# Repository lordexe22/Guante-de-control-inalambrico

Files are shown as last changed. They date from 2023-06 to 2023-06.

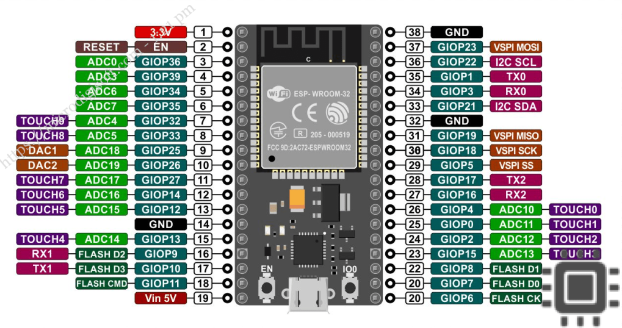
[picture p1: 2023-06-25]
imagenes/ESP32-pinout - Receptor.png

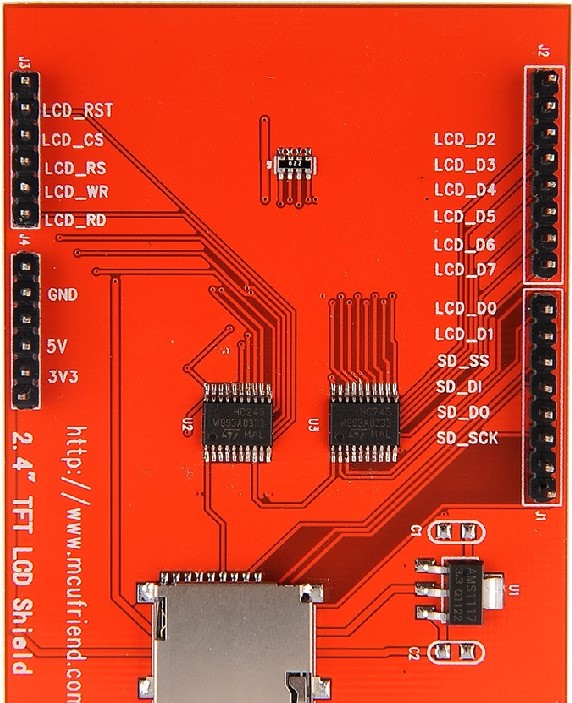
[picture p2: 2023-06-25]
imagenes/TFT-ILI9341-pinout.jpg

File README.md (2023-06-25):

# Guante de control remoto inalámbrico

## Secciones
- **Inforrmes**: En esta sección se encuentra el archivo ***informe.pdf*** en el cual se desarrolla en detalle el proceso de contrucción del proyecto.
- **PCB**: Contiene los archivos de desarrollo de los PCB de las distintas placas involucradas en el proyecto, también se incluyen los PDF con la carilla lista para imprimir cada una de las placas.
- **imagenes**: Catálogo de imágenes usadas para el desarrollo del informe
- **sensores**: Catálogo de imágenes de los sensores implementados en el proyecto, las mismas son usadas para el modelado 3D y las animaciones usadas en la presentación.
- **Sketchs**: Contiene el código implementado en los módulos ESP32 y en el ATMEGA328P, donde:
    - **ESP32emisor** es el código de control del ATMEGA328P con el cual se controla la pantalla táctil
    - **ESP32receptor** es el código del ESP32 que actua como transmisor de datos en el guante
    - **ESP32receptor_brazo** es el código del ESP32 que actua como receptor de datos en la placa conectada al brazo robótico
___
## Presentación
https://www.youtube.com/watch?v=zHHjbapvvzc

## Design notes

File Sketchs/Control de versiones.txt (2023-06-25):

TFTLCD_V1.0 >> las opciones de la pantalla tactil se eligen y se le da a la opcion de reproducir para enviar el codigo correspondiente

TFTLCD_V1.1 >> ahora las opciones se seleccionan presionando dos veces el boton de interes
            >> se agrego el comando "reproducir rutina" con lo cual podemos observar el estado de las rutinas generadas en la memoria SD 

----------------------------------------------------------------------------------------------------------------------------------------------------------

ESP32emisor_V1.0 >> version sin terminar, funcionaba con la mayoria de ordenes a excepcion de la orden "transmitir rutina"

ESP32emisor_V1.1 >> se agrego un algoritmo para poder transmitir una rutina al receptor
                 >> funcional con todas las ordenes a excepcion de la orden "reproducir rutina"

ESP32emisor_V1.2 >> el programa trabaja con un solo tipo de estructura que unifica tanto los datos de configuracion como los datos leidos de los sensores
		 >> se agrega una nueva funcionalidad para reproducir una rutina seleccionada en el receptor
                 >> se corrige el booleano que indica la fase o etapa en la cual nos encontramos dentro de la tarea solicitada (b_esDato)

----------------------------------------------------------------------------------------------------------------------------------------------------------

ESP32receptor_V1.0 >> version sin terminar, tiene implementadas todas las funcionalidades que trabajan con los datos enviados por el transmisor, esto 
		   >> incluye todos los usos de la memoria

ESP32receptor_V1.1 >> se incluyen todas las funcionalidades relacionadas con los sensores que activan las rutinas, en esta version los valores se 
                   >> envian por el puerto serial sin modificaciones (version para usar en la simulacion)

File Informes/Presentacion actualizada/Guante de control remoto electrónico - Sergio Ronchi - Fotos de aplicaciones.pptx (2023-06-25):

## Guante de control remoto electrónico

BERARDI, Nahuel
PUIG, Walter
RONCHI, Sergio J. C.
Director de Tesis: VICARIO, Sebastián

## Fundamentación del proyecto

- El proyecto consiste en la elaboración de un guante de control electrónico inalámbrico dotado de sensores de movimiento, un sistema de almacenamiento de datos y una interface de usuario táctil.

## Diagrama en bloques del guante y del receptor

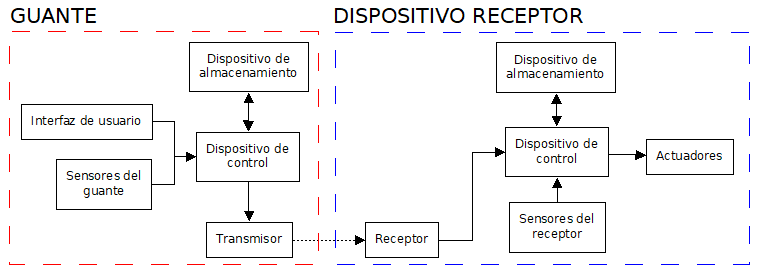
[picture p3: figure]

## Imagen del guante de ambos lados

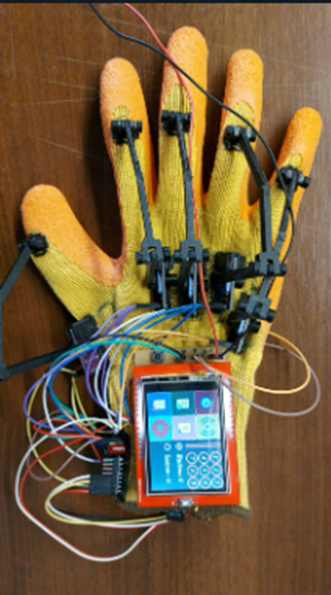
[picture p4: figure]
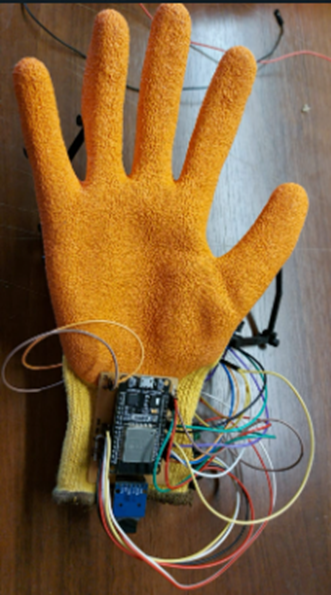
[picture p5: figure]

Sensores de Movimiento

Núcleo ESP32

Pantalla LCD

Módulo de memoria

LEDS

## Sensores de movimiento del guante

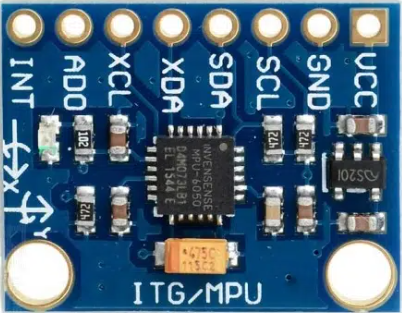
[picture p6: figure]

Acelerómetro
Giróscopo

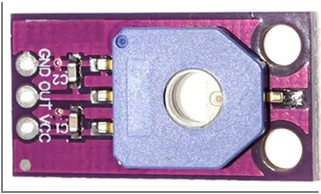
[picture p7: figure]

Sensor de giro

## MENÚ DE PANTALLA

Cambiar sensor

Reproducción en tiempo real

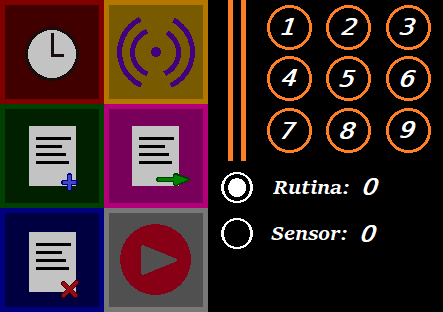
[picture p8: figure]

Teclado Numérico

Transmitir rutina

Crear nueva rutina

Seleccionar Rutina

Borrar rutina

Seleccionar Sensor

Reproducir rutina

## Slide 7

- Seguiría con diagramas en bloque del funcionamiento del guante

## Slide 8

- Acá ocuparíamos 3 ó 4 diapos para el brazo

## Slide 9

- Video de movimiento del guante y del brazo

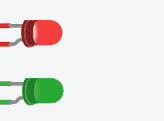
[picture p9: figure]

## Para qué serviría? aplicaciones

- Disponer de un guante con 11 grados de libertad, es decir, 11 datos de movimientos, independientes entre sí, nos abre un abanico bastante amplio de aplicaciones a implementar.
- Por un lado, y en nuestro ejemplo, estamos moviendo un brazo robótico, en tiempo real, o a través de rutinas guardadas.
- Pero podríamos implementar este guante, en otras aplicaciones, tales como:
- Maniobrar un dron.
- Interactuar con realidad virtual, o realidad aumentada.
- Usarlo como periférico para un video juego.

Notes: Disponer de un guante con 11 grados de libertad, es decir, 11 datos de movimientos, independientes entre sí, nos abre un abanico bastante amplio de aplicaciones a implementar.
Por un lado, y en nuestro ejemplo, estamos moviendo un brazo robótico, en tiempo real, o a través de rutinas guardadas.
Pero podríamos implementar este guante, en otras aplicaciones, tales como:
Maniobrar un dron.
Interactuar con realidad virtual, o realidad aumentada.
Usarlo como periférico para un video juego.

## Para qué serviría? aplicaciones

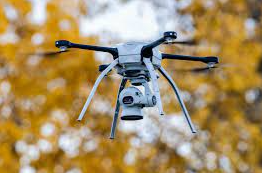
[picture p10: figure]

Dirigir un dron

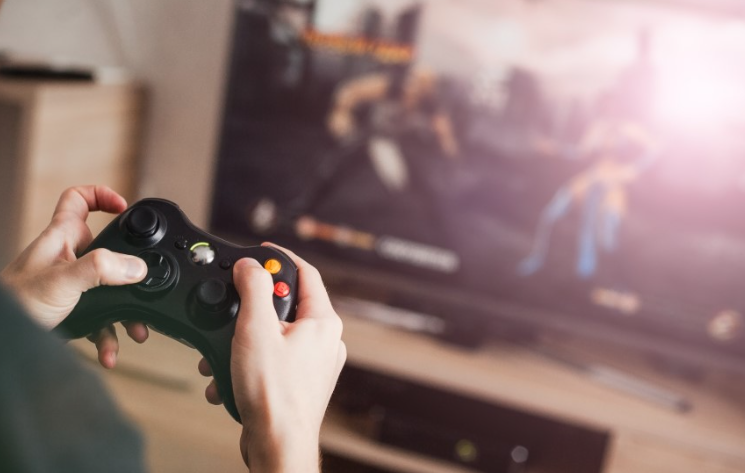
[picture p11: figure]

Videojuegos

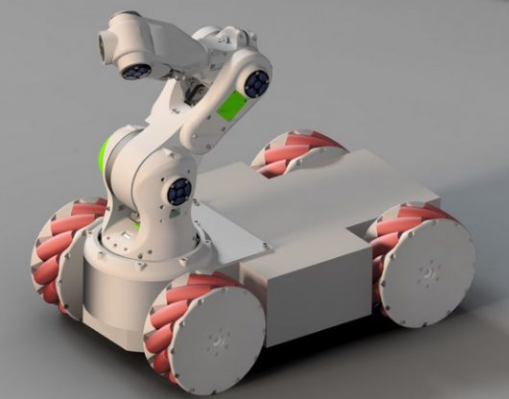
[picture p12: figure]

Vehículo Robot

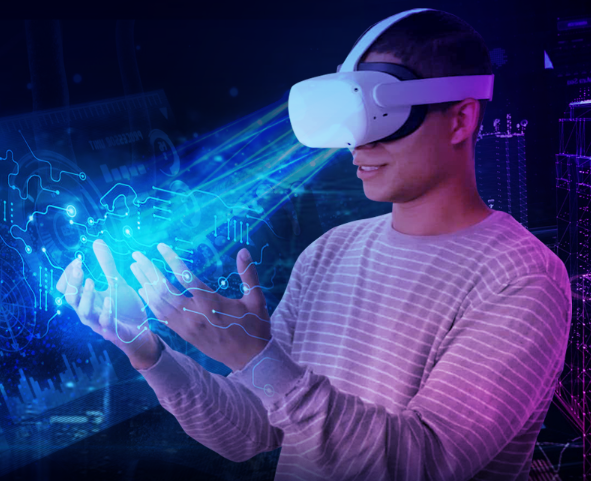
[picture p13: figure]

Realidad Virtual

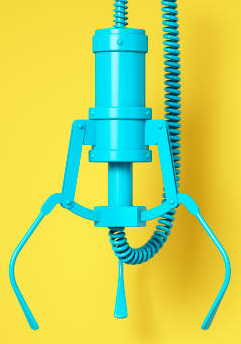
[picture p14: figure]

Garra Robótica

## Alguna pregunta del comité evaluador?

## Gracias por su atención

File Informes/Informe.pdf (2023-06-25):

## Universidad Tecnológica Nacional

## Proyecto Final

# Guante de control remoto electrónico

Autores:

- Berardi, Nahuel Matías
- Puig, Walter Ezequiel
- Ronchi, Sergio Juan Carlos

Director:

- Vicario, Sebastián

Proyecto final presentado para cumplimentar los requisitos académicos

para acceder al título de Ingeniero Electrónico en la

## Facultad Regional Paraná

Diciembre de 2022

## Declaración de autoría:

Yo/nosotros declaro/declaramos que el Proyecto Final “Guante de control remoto” y el trabajo realizado son propio/s. Declaro/declaramos:

- Este trabajo fue realizado en su totalidad, o principalmente, para acceder al título de grado de Ingeniero Electrónico, en la Universidad Tecnológica Nacional, Regional Paraná.
- Se establece claramente que el desarrollo realizado y el informe que lo acompaña no han sido previamente utilizados para acceder a otro título de grado o pre-grado.
- Siempre que se ha utilizado trabajo de otros autores, el mismo ha sido correctamente

citado. El resto del trabajo es de autoría propia.

- Se ha indicado y agradecido correctamente a todos aquellos que han colaborado con el presente trabajo.
- Cuando el trabajo forma parte de un trabajo de mayores dimensiones donde han

participado otras personas, se ha indicado claramente el alcance del trabajo

realizado.

Firmas:

•

•

•

Fecha: 30/12/2022

## Agradecimientos:

En primer lugar, deseamos expresar nuestro agradecimiento a Sebastián Vicario, nuestro profesor guía en este Proyecto Final. Él ha sabido acompañarnos y guiarnos en

este trayecto tan importante de nuestra carrera, poniendo su tiempo a nuestra disposición, y brindando su vasto conocimiento y experiencia, sin dejar de lado su constante buen humor. ¡Gracias Sebastián!

A la comunidad educativa de la Universidad Tecnológica Nacional, Facultad Regional

Paraná que nos brindaron el lugar y las herramientas necesarias para desarrollar este proyecto.

Berardi, Nahuel Matías

Puig, Walter Ezequiel

Ronchi, Sergio Juan Carlos

## Universidad Tecnológica Nacional

# Abstract

## Facultad Regional Paraná

## Ingeniero en Electrónica

# Guante de control remoto electrónico

Berardi, Nahuel Matías

Puig, Walter Ezequiel

Ronchi, Sergio Juan Carlos

Abstract:

This article seeks for the incorporation of new technologies in remote applications

that require performing repetitive tasks through a peripheral based on an electronic control

glove.

The project consists in the elaboration of an electronic control glove equipped with

movement sensors, a data storage system and a tactile user interface. It is sought that it be

able to control other electronic devices in real time and on the other hand that can create, transmit and reproduce movement routines that are activated by a sensor of the receiving

device. To achieve this, not only the glove is enough, it is necessary to implement a control module that commands the receiving device, which in this case is a robotic arm, which is why an appropriate circuit must be made for its control.

For its elaboration, the communication and control system between both devices is based on the ESP32 wireless module, the data storage is done through SD memory reader

modules, the mechanical system of the glove and the robotic arm were elaborated by means of 3D printing, Movement capture was done with gyro sensors and the module with accelerometer and gyroscope MPU6050. Finally, the user interface consists of a touch LCD

screen controlled by an ATMEGA328P on the glove and a 2x16 LCD screen on the receiver

plate incorporated into the arm.

The result obtained is a system that allows the user to remotely control the robotic arm in real time and store movement routines in the SD memory so that they can be

reproduced when one of the sensors connected to it is activated. However, as the system is similar for any type of receiver, it has the potential to control other devices such as drones,

robots, toys, and more.

Keywords:

Data

Memory

Movement

Routine

Wireless

Resumen:

Este artículo busca la incorporación de nuevas tecnologías en aplicaciones remotas

y que requieran realizar tareas repetitivas mediante un periférico basado en un guante de control electrónico.

El proyecto consiste en la elaboración de un guante de control electrónico inalámbrico dotado de sensores de movimiento, un sistema de almacenamiento de datos y una interface de usuario táctil. Se busca que sea capaz de controlar otros dispositivos

electrónicos en tiempo real y por otro lado que pueda crear, transmitir y reproducir rutinas de movimientos que sean accionadas mediante la activación de algún sensor del dispositivo

receptor. Para lograr esto no solo basta con el guante, sino que es necesario implementar un módulo de control que comande el dispositivo receptor, el cual en este caso es un brazo

robótico, es por esto que se debe realizar un circuito acorde para su control.

Para su elaboración, el sistema de comunicación y control entre ambos dispositivos está basado en el módulo inalámbrico ESP32, el almacenamiento de datos se hace

mediante módulos de lectores de memoria SD, el sistema mecánico del guante y del brazo robótico fueron elaborados mediante impresión 3D, la captura de movimientos se realizó

con sensores de giro y con un módulo que incorpora un acelerómetro y un giroscopio en un solo chip (MPU6050). Finalmente, la interface de usuario está constituida por una pantalla

LCD táctil controlada por un ATMEGA328P en el guante y una pantalla LCD de 2x16 en la

placa receptora incorporada al brazo.

El resultado obtenido es un sistema que le permite al usuario controlar remotamente en tiempo real el brazo robótico y almacenar rutinas de movimiento en la memoria SD para que sean reproducidas al activarse uno de los sensores conectados al mismo. Sin embargo,

como el sistema es similar para cualquier tipo de receptor, tiene el potencial para controlar otros dispositivos como drones, robots, juguetes y más.

Palabras Clave:

Datos

Inalámbrico

Memoria

Movimiento

Rutina

## Índice:

1.4.2. DEXTAROBOTICS DEXMO haptic feedback exoskeleton gloves.........3
2.8. Procesamiento de la información (acelerómetros/giroscopios/sensores).....33

5.3. Comparar con otros productos existentes a modo debate. Remarcando

## Lista de Figuras:

Figura 19: a) Principio de funcionamiento del Acelerómetro, b) Arquitectura interna

Figura 22: Variación de los ejes del acelerómetro cuando se lo rota sobre un eje .21

Figura 33: Conexionado de los botones de start, stop, el potenciómetro selector y el

Figura 39: Imagen del conexionado del servomotor de la muñeca con la palma....42

Figura 40: Ubicación del servomotor de la muñeca dentro de la impresión 3D ......43

## Lista de Tablas:

## Lista de Abreviaciones y Símbolos

## Lista de abreviaciones

LiPo | Litio y polímero
SCM | Supply Chain Management (Administración de la cadena de suministro)
SD | Secure Digital
LCD | Liquid Cristal Display (pantalla de cristal líquido)
PCB | Printed Circuit Board (placa de circuito impreso)
HMI | Human-Machine Interface (interfaz humano-maquina)
n° | Número
IMU | Inertial Measurment Units
MEMS | MicroElectroMechanical Systems
[°/s] | Grados por segundo
MPU | Multiple Process Unit (Unidad de proceso múltiple)
HTML | HyperText Markup Language (Lenguaje de Marcas de Hipertexto)
CSS | Cascading Style Sheets (hojas de estilo en cascada)
ROM | Read Only Memory (‘memoria de solo lectura’)
SDHC | Secure Digital High Capacity
MAC | Media Access Control
I2C | inter integrated circuits
ms | mili-segundos
ADC | Analog to Digital Converter (Conversor Analógico Digital)

## Lista de símbolos

a | Aceleración
dV | Diferencia de velocidad
dt | Diferencia de tiempo
F | Fuerza
m | Masa
θX | Angulo de inclinación con respecto al eje X
θY | Angulo de inclinación con respecto al eje Y
aX | Acelerómetro del eje X
aY | Acelerómetro del eje Y
aZ | Acelerómetro del eje Z
θX0 | Angulo con respecto al eje X anterior
θY0 | Angulo con respecto al eje Y anterior
ωX | Velocidad angular con respecto al eje X
ωY | Velocidad angular con respecto al eje Y
∆t | Intervalo de tiempo
a(PWM) | Valor de la aceleración para luego generar la PWM
amax | Máximo valor del acelerómetro
amin | Mínimo valor del acelerómetro
k | Constante de ajuste
gx | Valor de la velocidad angular sobre el eje X leído del giroscopio
gactual | Valor de la velocidad angular en la medición actual leído del giroscopio
ganterior | Valor de la velocidad angular en la medición anterior leído del giroscopio
tactal | Valor del tiempo de la medición actual
tanterior | Valor del tiempo de la medición anterior

## Dedicado a:

Un trabajo de desarrollo es también fruto del reconocimiento y del apoyo vital que

nos ofrecen las personas que nos estiman, sin las cuales no tendríamos la fuerza y energía que nos anima a crecer como personas y como profesionales.

Es por esto que deseamos dedicarle este informe a aquellas personas que han estado con nosotros a lo largo de todos estos meses brindándonos su apoyo de manera

incondicional.

Berardi Nahuel:

Este proyecto lo dedico principalmente a mi mamá y mi papá, quienes me han brindado su apoyo y contención a lo largo de estos años, gracias a eso pude dedicarme por completo a esta etapa de mi vida. Hago una especial dedicatoria a mi hermana, que siempre

está presente para motivarme y consolarme cuando lo necesito, es la persona que me apoya para seguir adelante, sin importar el tipo de problema que enfrente.

Finalmente, y no menos importante, a mis amigo y seres queridos por motivarme a continuar ¡gracias a todos!

Puig Walter:
Mi dedicatoria va principalmente para mi familia quienes me han brindado su amor y

apoyo a lo largo de estos años para permitirme dedicarme al 100% a superar esta etapa de mi vida. Le hago una dedicatoria especial a Sol quien sin saberlo me ha sabido contener en

las malas y me ha prestado un oído siempre que necesite hablar con alguien. Finalmente, y no menos importante a mi equipo de trabajo con los cuales hemos trabajado codo a codo para finalizar este proyecto y cumplir nuestras metas, ¡gracias a todos!

Ronchi Sergio:

A mis padres, Azucena y Pedro, que desde el Cielo están celebrando este momento.

A mi esposa Patricia, y a mis hijas Delfina y María Paz, nada podría funcionar sin

ellas…

¡A mis amigos y seres queridos, gracias por motivarme siempre a seguir!

1 Introducción | 1

## Capítulo 1: Introducción

1.1. Fundamentación del proyecto.

El proyecto propuesto es un guante de transmisión y control de datos, cuya finalidad es brindarle al usuario la posibilidad de crear fácilmente un conjunto de rutinas de trabajo

que sean accionables mediante sensores o pulsadores sin la necesidad de programar cada

uno de los movimientos que llevará a cabo el dispositivo electrónico que se desee controlar.

Inicialmente el proyecto fue planteado para aplicarse en sistemas de producción que

requieran de un conjunto de rutinas de movimiento repetitivas en el tiempo y que sean accionadas por un sensor. Sin embargo, también se extiende a la posibilidad de controlar

dispositivos de manera remota y en tiempo real, lo cual brinda la funcionalidad adicional de

poder utilizarlo en aplicaciones de alto riesgo, incluso como un medio de entretenimiento (para controlar dispositivos como drones, vehículos de control remoto y periféricos para consolas o PC).

Para esto se propone la creación de un guante de control que estará dotado de varios

sensores que detectarán los movimientos realizados por el usuario y un sistema de transmisión de datos que enviará esta información hacia el dispositivo electrónico que se

desee controlar. La idea es que el guante le permita al usuario tanto la creación, como la gestión y el guardado de distintas rutinas de movimientos que deben ser leídas e

interpretadas por otros dispositivos electrónicos para ejecutar una o varias acciones.

Para lo anterior, es imprescindible que el guante permita el control de dispositivos en tiempo real de forma remota, esto con la finalidad de llevar a cabo tareas manualmente o

bien para darse una idea de cómo se comportarán algunas de las rutinas que se deseen implementar.

### 1.2. Público objetivo

El público objetivo de este proyecto está orientado a toda industria o institución que

se vea en necesidad de controlar remotamente en tiempo real o mediante una rutina de movimientos algún dispositivo electrónico. Sin embargo, según la orientación que tome el proyecto en futuras versiones, podría tener demanda en distintas áreas enfocadas al

entretenimiento.

1 Introducción | 2

Este prototipo brinda facilidades para realizar trabajos que emplean rutinas de movimientos repetitivos como los que se llevan a cabo en cadenas de producción, en dispositivos de maniobras (cocinero inteligente, cama de masaje inteligente, asistentes de

laboratorio, etc.), permitiéndole al usuario la programación de las rutinas necesarias para ejecutar el trabajo deseado. A su vez también permite el control de dispositivos en tiempo

real, lo cual permite al usuario utilizarlo en una amplia gama de aplicaciones que pueden ir desde su uso en trabajos potencialmente peligrosos hasta sistemas de entretenimiento.

### 1.3. Pruebas de concepto

Las prestaciones podrían garantizar, en general, un trabajo más eficiente. Cuando se lo usa en tiempo real de forma remota, un operario que efectúa un trabajo de riesgo,

puede maniobrar en una situación de estrés mucho menor que si estuviera realizando un trabajo riesgoso de manera presencial, lo cual lleva a realizar mejor la tarea.

Para el caso en el que se realizan tareas repetitivas, el proceso se vuelve más económico al no requerir de un empleado que efectúe el trabajo manualmente y más

confiable ya que reduce el margen de error por fatiga.

### 1.4. Análisis de mercado

1.4.1. Guante somatosensorial basado en arduino.

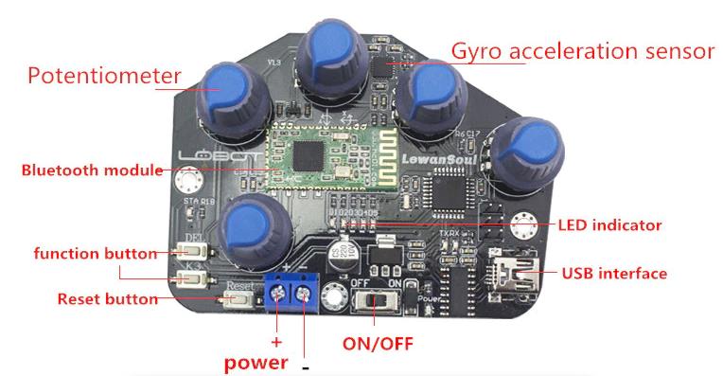
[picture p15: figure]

Figura 1: Guante somato sensorial

Se trata de un guante somato sensorial pensado para la comunicación y control de

distintos tipos de dispositivos. Este modelo comercial permite el control de los dispositivos mostrados en la imagen mediante la aplicación de gestos predefinidos para tal fin.

1 Introducción | 3

Características:

- Guante mecánico de código abierto basado en Arduino; Modelo de chip único:

ATmega328P

- Esquema abierto y código fuente;
- El módulo Bluetooth 4,0 integrado y el sensor de aceleración;
- Proporciona un gran número de rutinas de control que pueden controlar la palma del robot, el brazo robótico, el robot biónico, el coche inteligente

Parámetros del producto:

Modelo de microcontrolador: Arduino

Batería: 7,4 V 2S lipo-batería (integrada)

Tamaño: 147[mm] x 113[mm]

Peso: 0,26[kg]

Precio aproximado: 100 USD

El guante se usa para controlar el robot, el módulo Bluetooth del robot debe trabajar en HC-08. Basado en el Protocolo Bluetooth 4,0.

### 1.4.2. DEXTAROBOTICS DEXMO haptic feedback exoskeleton gloves

Este modelo lee los movimientos que se llevan a cabo con el guante capturando hasta 11 grados de libertad y además su tecnología le brinda al usuario la sensación de

tacto cuando se lo utiliza en entornos de simulación de realidad virtual.

Figura 2: Dextarobotics dexmo

1 Introducción | 4

Para conseguir este efecto, los guantes utilizan un sistema que aplica un torque justo en la dirección contraria a la cual se efectúa el movimiento de la mano, es decir, para conseguir que tengas la sensación de que tus dedos chocan con algo, un mecanismo tira

de ellos hacia atrás justo en el momento preciso.

Dexmo es el guante de retroalimentación de fuerza más portátil del mundo

para investigadores, empresas y consumidores. Proporciona un toque natural e intuitivo que da un toque íntimo del mundo de RV verdaderamente inmersivo.

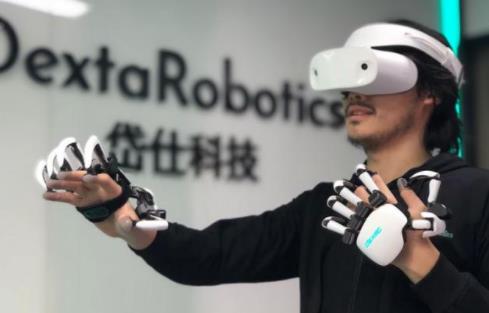
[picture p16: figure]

Figura 3: Dextarobotics dexmo

Dexmo es el primer guante portátil de retroalimentación de fuerza inalámbrica de dos

manos disponible comercialmente del mundo, con captura de movimiento de mano y retroalimentación de fuerza para una experiencia interactiva de retroalimentación de fuerza

más emocionante. Tiene aplicaciones en el área aeroespacial, formación industrial, investigación educativa, rehabilitación médica, modelado de simulación, socialización de juegos y más.

Características:

- Habilidad de capturar movimientos: Dexmo captura un rango completo de

movimientos de la mano del usuario y posee dos grados de libertad en la captura de movimiento de los dedos, permitiendo capturar los movimientos de flexión y

abducción de los mismos.

- Fuerza de respuesta variable: Le permite al usuario sentir el tamaño y la forma de cualquier objeto digital. Los motores detienen la rotación de los dedos de acuerdo al

avatar digital con la que tiene interacción la mano dentro del mundo digital. Dexmo

1 Introducción | 5

también es capaz de generar una fuerza de salida variable, permitiendo al usuario detectar la diferencia en la rigidez de los objetos y detectar por ejemplo la diferencia

entre una piedra y una pelota.

- Simulación de múltiples capas de rigidez: Al combinar el control de software con la capacidad de retroalimentación de fuerza variable, los desarrolladores pueden

describir fácilmente la rigidez de un objeto a través de las librerías de Dexmo y lograr una sensación háptica compleja. Cuando hay un cambio en la rigidez, se pueden

lograr sensaciones como presionar un botón y romper un huevo.

- Mejora de la seguridad: Dexmo está diseñado para ser seguro. La función de

control de salida del par motor controla la fuerza ejercida por el dedo del usuario y desactiva todas las funciones del motor en circunstancias anormales. Además, la salida de torsión máxima de cada módulo de retroalimentación de fuerza de cada

dedo está sujeta a 3[kg.cm] (0,3[N.m]). Un dedo humano puede proporcionar un torque promedio de 7[kg.cm] (0.7[N.m]). Entonces Dexmo nunca causará lesiones.

- Soporte de plataforma: Dexmo viene con su propio SDK, Lib Dexmo. Junto con el complemento de Unity que escribimos, Dexmo funciona con Oculus CV1, HTC Vive,

PSVR, Hololens y potencialmente con cualquier otra solución de VR/MR compatible

con el desarrollo de Unity.

- Comunicación inalámbrica: Comunicación inalámbrica con módulos de 2.4[GHz]

con protocolos de comunicación optimizados, con latencia de 20-50[ms] y rangos de funcionamiento de 5 metros.

- Ligero y portátil: Gracias al diseño liviano de los motores, Dexmo pesa solo 320[g], mientras que los productos existentes que ofrecen funcionalidades similares

generalmente pesan 10 veces más. Permite a los usuarios usar Dexmo cómodamente e ignorar su presencia cuando exploran en realidad virtual.

- Hasta 6 horas de duración de la batería: con los confiables y potentes módulos de batería LiPo de 2000[mAh], Dexmo puede funcionar de forma inalámbrica durante 6

horas con un uso normal.

Precio aproximado: 800 USD

1 Introducción | 6

### 1.4.3. Guantes de control de movimiento Keywish Autos Smart

Figura 4: Guantes de control de movimiento Keywish Autos Smart

El dispositivo de guante de movimiento puede calcular la dirección de inclinación de la palma de 0 a 360 grados en tiempo real. De acuerdo con estos dos parámetros, los usuarios pueden controlar cualquier dispositivo bluetooth, que es adecuado para otros autos inteligentes SCM u otros hogares inteligentes.

Características:

- Guante deportivo de código abierto basado en Arduino; Modelo de chip único: ATmega328P
- Esquema y código de fuente abiertos;
- Posee un módulo Bluetooth y un sensor de aceleración;
- Proporciona una determinada cantidad de rutinas de control que pueden controlar el coche inteligente.

Parámetros del producto:

Modelo de microcontrolador: Arduino

Batería: 9[V]

Precio aproximado: 40 USD

### 1.5. Conclusiones

1 Introducción | 7

En el mercado existe una interesante variedad de guantes con características bien definidas y que se pueden orientar a aplicaciones diferentes. Existen prototipos que proponen una aplicación de los mismos como juguetes educativos, juegos interactivos o

entretenimiento. El diseño implementado en este proyecto busca desde un inicio incorporar una tecnología que, si bien ya existe, no se ve implementada en los campos de interés

mencionados. La intención de este proyecto es sentar las bases para diseñar y construir una herramienta orientada al área industrial y de automatización, sin embargo, por lo visto

hasta ahora la naturaleza del diseño de este prototipo permite darle una gran flexibilidad y con ello la capacidad de poder ampliar su público objetivo y su área de aplicación.

2 Desarrollo | 8

## Capítulo 2: Desarrollo

2.1. Introducción.

El proyecto consiste en un guante al cual se le implementan un conjunto de módulos que le permitirán al usuario la gestión y control de rutinas que se guardan y modifican dentro de una memoria SD. El diagrama en bloques del guante es el siguiente:

Figura 5: diagrama en bloques del guante

En términos generales, los bloques funcionan de la siguiente forma:

- Interfaz de usuario: El usuario interactúa con las opciones disponibles y crea un código acorde, el cual, será enviado al dispositivo de control para efectuar

la tarea solicitada.
- Sensores del guante: Brindan información acorde a la posición de la mano y

los dedos.
- Dispositivo de almacenamiento: Guarda la información acorde a los diferentes tipos de configuraciones y a las rutinas almacenadas.
- Dispositivo de control (guante): Gestiona todos los bloques, ejecuta las tareas solicitadas y evalúa posibles problemas o conflictos para prevenir errores.
- Emisor y receptor: Establecen el medio por el cual se podran comunicar el guante y el dispositivo receptor.
- Dispositivo de control (receptor): Despues de recibir una orden desde el guante, gestiona la memoria y los datos para poner en funcionamiento los

actuadores propios del dispositivo receptor en caso de que así se requiera. Adicionalmente, detecta de manera constante los sensores propios conectados en el receptor, que al activarse ejecutarán la rutina vinculada al mismo. Los datos dentro de la rutina deben ser modificados acorde al tipo de aplicación para lo cual se los utilice.
- Sensores del receptor: Puede tratarse de cualquier tipo de sensor o pulsador

lógico. Cada sensor tiene asignado un número y al activarse el circuito de

control debe reproducir la rutina vinculada al sensor activado.
- Actuadores (receptor): Son propios del dispositivo receptor conectado al

dispositivo de control.

2.2. Funcionamiento general.

El guante posibilita la creación de hasta nueve rutinas, las cuales deben estar vinculadas a un número de sensor. Por ejemplo, si se crea la rutina uno y se la vincula al

sensor tres, entonces cuando en el receptor se active el sensor tres se ejecutará la rutina uno desde la memoria SD del dispositivo receptor. En la siguiente imagen se observa dentro

de la memoria SD que se han creado las rutinas 1, 2, 4 y 6.

Figura 6: Contenido de la memoria SD

La memoria SD cuenta con un archivo llamado Lista.txt en el cual se listan los pares (n° rutina , n° sensor) y al crearse una rutina, por ejemplo la rutina 1, se crea un archivo

‘Rutina_1.txt’ en la cual almacenará los valores que lea en los sensores al momento de su creación. Al abrir el archivo Lista.txt podemos observar a que número de sensor están

vinculadas las rutinas.

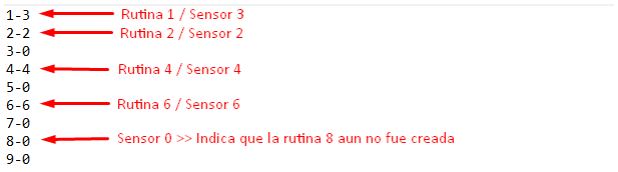
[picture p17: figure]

Figura 7: Contenido del archivo Lista.txt

Si abrimos los archivos de las rutinas, veremos los valores sensados durante su creación.

El guante permite realizar las siguientes operaciones:

1- Reproducción de datos en tiempo real: En este modo el guante lee los sensores y transmite sus valores al dipositivo receptor a una determinada frecuencia. El receptor por su parte, interpreta estos valores y ejecuta una acción acorde a los valores recibidos.

2- Transmisión de rutina: Se envia la configuración (n° rutina , n° sensor) y los valores leídos desde la memoria SD del emisor hacia la memoria SD del receptor.

3- Crear rutina: Crea una rutina y la almacena en la memoria SD del guante. Para ello modificará el par (n° rutina , n° sensor) y leerá los sensores del guante a una frecuencia determinada para almacenar esos valores en la memoria SD.

4- Cambiar sensor: Cambia el número del sensor vinculado a una rutina ya creada dentro de la memoria SD en el archivo Lista.txt, posteriormente transmite un código al dispositivo receptor para que haga lo mismo en su correspondiente memoria SD.

5- Borrar rutina: Elimina la rutina indicada. Para ello, primero actualiza el archivo Lista.txt haciendo que el valor del sensor vinculado a la rutina sea cero, luego elimina el archivo de la rutina indicada, y finalmente envía una orden al receptor para que haga lo mismo en su respectiva memoria SD.

6- Reproducir rutina: Esta modalidad permite seleccionar una rutina ya creada dentro de la memoria SD del guante y reproducirla en tiempo real una vez en el receptor sin guardarla en la memoria del mismo.

### 2.3. Interfaz de usuario:

Este bloque está compuesto por la pantalla LCD táctil ILI9341 y el microcontrolador ATMEGA328P. En principio se habia considerado utilizar una plantilla de pulsadores con una pantalla LCD de 2x16, pero la opción de la pantalla táctil nos otorga las siguientes prestaciones superadoras:

- Permite implementar una gran cantidad de botones en un espacio compacto, ahorrando en este caso la implementación de un PCB con al menos 15 pulsadores y una pantalla LCD de 2x16 o mayor.
- Brinda una interfaz más amigable con el usuario, permitiendo la visualización de la configuración realizada y el estado actual del guante.
- HMI más elegante, compacta y profesional.
- Totalmente controlable con el microcontrolador ATMEGA328P.

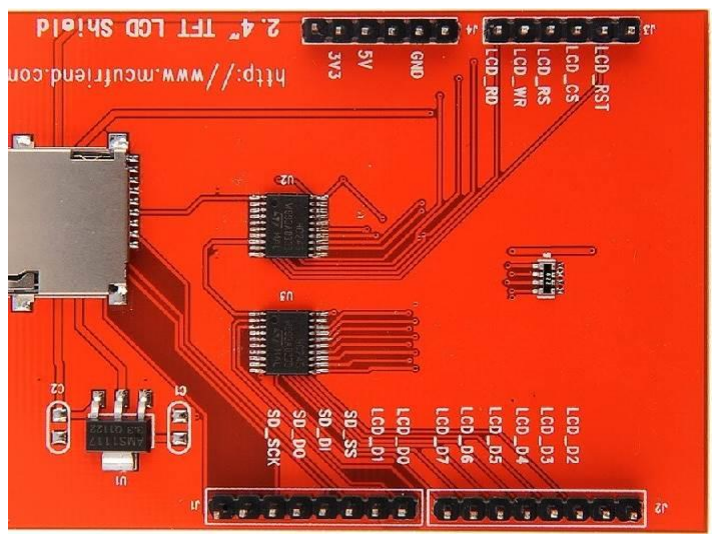
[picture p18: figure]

Figura 8: Pantalla LCD táctil ILI9341 vista de frente y reverso

Figura 9: Atmega328P

Figura 10: Pinout del Atmega328P

El esquema propuesto para la HMI es el siguiente:

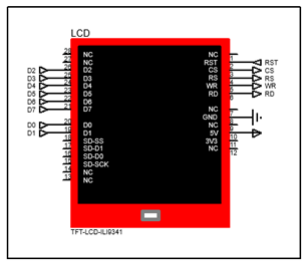
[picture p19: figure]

Figura 11: Conexionado del Atmega328P | Figura 12: Conexionado de la pantalla LCD ILI9341

Figura 13: Puertos de alimentación, oscilador y botón de reset del HMI

El esquema es una conexión básica del microcontrolador con el circuito oscilador y el botón de reset. También cuenta con tres puertos, de los cuales dos de ellos son de

alimentación (uno de entrada y uno de salida) y el otro es para comunicar mediante protocolo UART el ATMEGA328P con el ESP32 del bloque de control. Finalmente se

conecta el microcontrolador con la pantalla LCD táctil, los pines RST, CS, RS, WR y RD se usan para reiniciar la pantalla y que la misma permita visualizar la información,

adicionalmente con la ayuda del resto de los pines (D0 a D7) logramos controlar la componente táctil de la pantalla, que entre otras cosas retorna las coordenadas X, Y y la

presión ejercida sobre la misma, permitiendo saber en qué zona de la pantalla se ejerce presión.

Una vez conocido el esquema implementado para la HMI, queda conocer el software que se implementa sobre el mismo. Para esto se presenta el menú de la pantalla:

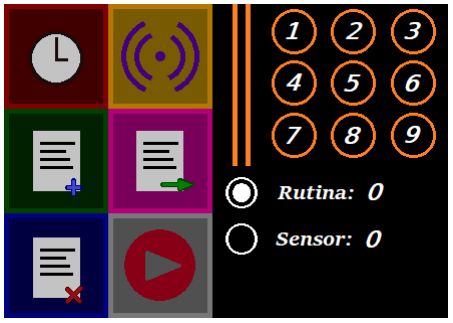
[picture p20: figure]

Figura 14: Diseño de la interfaz del HMI

En la mitad izquierda de la pantalla se hallan los botones correspondientes a las diferentes tareas disponibles, mientras que a la derecha tenemos un teclado numérico y un

selector de rutina y de sensor, que nos permiten indicar sobre qué conjunto se realizará la tarea indicada. Para efectuar una tarea en concreto se deben seleccionar (de ser necesario)

el número de la rutina y del sensor que se involucran en la tarea y posteriormente pulsar dos veces el icono correspondiente. Durante el primer pulso el botón se iluminará y en el segundo quedará marcado con un recuadro rojo indicando que la tarea esta activa.

Figura 15: Estados de los botones de la interfaz del HMI

Si no se presiona por segunda vez el botón, este se “apaga”. A continuación se

presenta una tabla que indica el tipo de datos necesario para cada tarea.

Tarea | ¿Requiere rutina? | ¿Requiere sensor?
1 – Reproducción en tiempo real | NO | NO
2 – Transmitir rutina | SI | NO
3 – Crear nueva rutina | SI | SI
4 – Cambiar sensor | SI | SI
5 – Borrar rutina | SI | NO
6 – Reproducir rutina | SI | NO

Finalmente se indica la tarea asociada a cada uno de los iconos presentados en la pantalla:

Reproducción en tiempo real | Crear nueva rutina
Borrar rutina | Cambiar número de sensor
Transmitir rutina | Reproducir rutina

La lógica dentro del comportamiento de la HMI queda detallada en el siguiente diagrama:

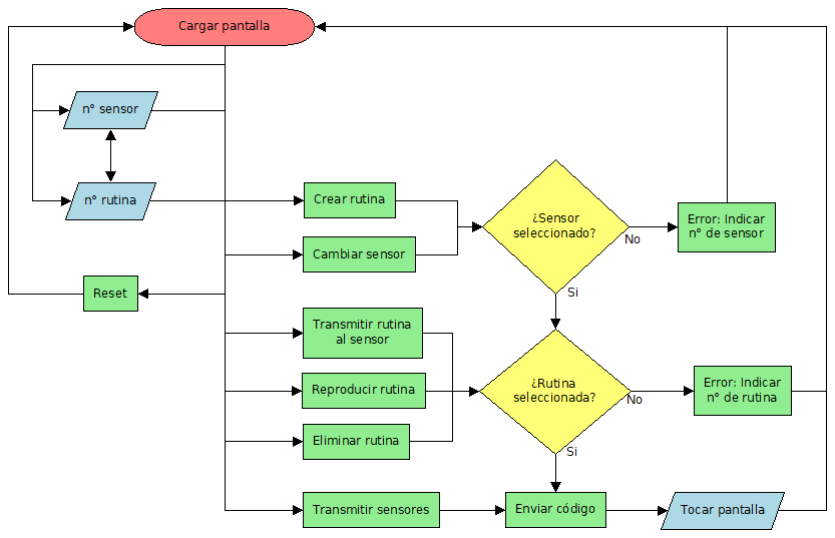
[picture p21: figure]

Figura 16: Diagrama de flujo de la interfaz del HMI

Inicialmente se carga la pantalla del menú principal. Desde este ese punto el usuario puede optar por modificar el número de sensor, el número de rutina, el botón de reset o

bien presionar dos veces alguno de los botones de tareas. Luego de intentar activar alguna tarea, se evalúa si se han llenado los campos necesarios para cada una de ellas y en caso

afirmativo envia un código acorde mediante comunicación I2C hacia el circuito de control.

En caso contrario se podra visualizar en la pantalla un mensaje indicando el campo que falta completar para efectuar la tarea solicitada. Para finalizar la tarea solicitada, basta con

volver a presionar la pantalla en cualquier lugar, esto enviará un código de finalización hacia el circuito de control y reiniciará la pantalla LCD.

El código enviado consiste en tres números separados por guiones, el primero corresponderá a la tarea que se desea ejecutar, el segundo es el número de la rutina

involucrada y el tercero el número del sensor. La única excepción sera el código de cierre para indicar que se desea terminar con la tarea solicitada. Este último código sera 0-0-0.

2.4. Sensores del guante.

La función principal de los sensores en este proyecto es el de capturar los movimientos que el usuario efectúe al mover la mano o los dedos. Por un lado, para detectar

la flexión en los dedos las dos mejores dos opciones disponibles son resistencias flexibles y módulos de sensores de giro. Se pretende analizar cada opción y justificar la elección

tomada.

Resistencias flexibles:

Pros:

- Son mucho más simples de manipular y se pueden colocar directamente sobre el guante para que funcionen.

Contras:

- Requieren una conexión en serie de otra

resistencia en caso de que se desee leer la flexión por variación de tensión y no de corriente.

- Son considerablemente más costosas que los

sensores de giro.
- Son algo frágiles, por lo cual pueden quebrarse por

el desgaste al usarlas.

Figura 17: Resistencia flexible

Módulos de sensores de giro:

Pros:

- | Considerablemente | más | económicos | que | las
| resistencias flexibles.
- No requieren componentes externos, el valor de interés

puede obtenerse directamente de la salida del sensor.

- Compactos, precisos y con un buen rango de
| funcionamiento.

Contras:

- Debe suministrarse 3.3[V] a cada uno de los dispositivos para que funcionen.
- Debe considerarse que no tienen tope, por lo cual, al

girar y sobrepasar su valor máximo, conmutará al valor mínimo y viceversa.

- Requieren implementar un mecanismo externo para lograr rotar su eje al realizar el movimiento de los dedos.

Figura 18: Sensor de giro

Vistas las dos propuestas, se optó por el sensor de giro. La razón principal es que si

bien tienen la desventaja de requerir del diseño de un mecanismo externo que permita la rotación del eje del sensor al flexionar un dedo, esto puede tomarse como una posibilidad para escalar el proyecto y diseñar a futuro un mecanismo más complejo y que permita el

uso de más sensores de giro, permitiendo por ejemplo la lectura del movimiento lateral de los dedos y aumentando así los grados de libertad y la cantidad de señales que pueden

interpretarse. El diseño y la impresión 3D de los módulos para conectar los sensores se detallan al final del capítulo.

Ya analizados los sensores de los dedos, queda pendiente medir la posición y rotación de la mano en el espacio con respecto al codo. Para ello también optamos por dos

modelos. El primero y más sencillo es simplemente conectando algunos potenciómetros en las zonas próximas al codo y la muñeca, así el movimiento y giro de los mismos generarán

las variaciones que deseamos medir para saber que estamos efectivamente flexionando el codo o bien rotando la muñeca. La segunda opción, que finalmente fue la adoptada en este

proyecto, pese a resultar más compleja, pero mucho más interesante es la utilización de un módulo que cuenta internamente con un sistema de giroscopios y acelerómetros con los

cuales podamos saber exactamente como se está produciendo el movimiento de la mano en el espacio.

El módulo escogido es el MPU6050. Es una unidad de medición inercial o IMU

(Inertial Measurment Units) de 6 grados de libertad (DoF), este dispositivo combina un acelerómetro de 3 ejes con un giroscopio de 3 ejes. El acelerómetro mide la aceleración

gravitacional y el giroscopio la velocidad rotacional que experimenta el módulo. Este dispositivo se usa para determinar la orientación de un objeto en movimiento en el espacio (para nuestro caso particular será la mano).

La comunicación del módulo es por I2C, lo que le permite trabajar con la mayoría de

microcontroladores disponibles en el mercado. Los pines SCL y SDA tienen una resistencia pull-up en la placa para una conexión directa al microcontrolador.

El acelerómetro mide la fuerza gravitacional y puede detectar pequeños movimientos

o vibraciones.

En física, la aceleración es la variación de la velocidad por unidad de tiempo es decir razón de cambio en la velocidad respecto al tiempo: a=dV/dt.

Por otro lado, la segunda ley de Newton indica que, en un cuerpo con masa constante, la aceleración del cuerpo es proporcional a la fuerza que actúa sobre él mismo: a=F/m.

Este segundo concepto es utilizado por los acelerómetros para medir la aceleración. Los acelerómetros internamente tienen un MEMS (MicroElectroMechanical Systems) que

de forma similar a un sistema masa resorte permite medir la aceleración.

Figura 19: a) Principio de funcionamiento del Acelerómetro, b) Arquitectura interna del Acelerómetro

A pesar de que no exista movimiento, el acelerómetro siempre estará sensando la aceleración de la gravedad. Esto es particularmente útil, ya que al integrar la aceleración

nos permite medir de forma indirecta la velocidad del movimiento y la posición del objeto.

Para que un eje en particular tome valores máximos, éste debe estar en paralelo al vector fuerza de gravedad. Si alguno de los ejes apunta en el mismo sentido que la fuerza de gravedad (hacia abajo) adquiere un valor de -9.81, en cambio si apunta en sentido opuesto

(hacia arriba) adquiere un valor de 9.81.

Si el eje es perpendicular a la dirección de la gravedad, su acelerómetro será 0.

El giroscopio por otro lado, mide la velocidad angular sobre cada uno de los ejes del MPU6050 en [°/s]. En física la velocidad angular es la tasa de cambio del desplazamiento

angular sobre unidad de tiempo o, en otras palabras, que tan rápido gira un cuerpo sobre su propio eje.

Este dato es particularmente útil para detectar el sentido de movimiento de un objeto en el espacio. Si el sensor está estático, entonces todos los giroscopios medirán cero.

Los giroscopios utilizan un MEMS (MicroElectroMechanical Systems) para medir la

velocidad angular usando el efecto Coriolis.

El MPU6050 tiene tres ejes sobre la placa: los ejes x, y, z. Los mismos se usan para

representar el sentido positivo del acelerómetro y el giroscopio vinculado a cada eje. Se presenta una imagen representativa de esto último:

Figura 20: Orientación de los ejes del MPU6050

La implementación del MPU6050 requiere conocer el funcionamiento general que se

ha explicado previamente pero también necesita una calibración previa para corregir errores de offset generados por inclinaciones no deseadas (como el de la soldadura del chip MPU a su módulo o del montaje del módulo al circuito) y errores de medición acumulativos como

los que se generan en los giroscopios en ciclos muy largos de mediciones. Todos estos errores se corrigen calibrando por código algunas variables internas del MPU6050 con la

ayuda de las librerías que se diseñaron para el mismo.

Para la lectura y adquisición de datos, nos interesa obtener los ángulos de inclinación y de giro que presenta el MPU6050.

Para calcular el ángulo de inclinación, asumiremos que estamos en un plano X-Z e

inclinamos el MPU6050 un ángulo θ, dicho ángulo se calcula de la siguiente forma:

Figura 21: Cálculo de la componente del acelerómetro

Lo anterior nos sirve para calcular el ángulo en un plano 2D, pero, para calcular los ángulos de inclinación en un espacio 3D, tanto en X como en Y, usamos las siguientes

fórmulas:

Tener en cuenta que el resultado esta dado en radianes.

También es importante considerar que, si sólo trabajamos con el acelerómetro, éste

es susceptible a las aceleraciones producto del movimiento del MPU o a fuerzas externas, pero en tiempos largos el ángulo no acumula errores.

Para el cálculo de los ángulos de rotación, se trabaja con los valores obtenidos de los giroscopios. El giroscopio nos entrega la velocidad angular, y para calcular el ángulo

actual necesitamos integrar la velocidad y conocer el ángulo inicial. Esto lo hacemos usando la siguiente fórmula:

Tener en cuenta que θx es el ángulo que gira el eje X sobre su propio eje. En la siguiente imagen se observa que la velocidad angular es perpendicular al plano de rotación.

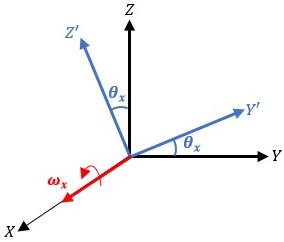
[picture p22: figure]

Figura 22: Variación de los ejes del acelerómetro cuando se lo rota sobre un eje

Es muy importante considerar que esta medida no es exacta ya que produce un error acumulativo en el tiempo (incluso varía cuando no se mueve el ángulo), o si se gira cierto

ángulo y luego se regresa a la posición original el ángulo que medimos no es el inicial. Esto se debe a que al integrar la velocidad angular y sumar el ángulo inicial hay un error producto

de la mala medición del tiempo o del ruido en la lectura del MPU. Este error, por más pequeño que sea, se va acumulando en cada iteración y creciendo, y es conocido como

DRIFT.

Para disminuir el drift existen varios métodos, la mayoría aplican filtros para eliminar

el ruido de las lecturas del sensor. También se pueden usar otros sensores como magnetómetros o acelerómetros y con los ángulos calculados con éstos mejorar el cálculo del giroscopio.

Un filtro muy usado para esto es el filtro de complemento, el cual es de fácil implementación y combina el ángulo calculado por el giroscopio con el ángulo calculado por

el acelerómetro. La ecuación para calcular el ángulo usando el filtro de complemento es:

De esta forma el ángulo del acelerómetro está pasando por un filtro pasa bajos,

amortiguando las variaciones bruscas de aceleración; y el ángulo calculado por el giroscopio tiene un filtro pasa altos teniendo gran influencia cuando hay rotaciones rápidas.

Podemos probar también con otros valores diferentes a 0.98 y 0.02 pero siempre deben de sumar 1.

Conocidas las bases de la programación del MPU resta realizar las conexiones

eléctricas correspondientes a la alimentación, a las líneas de comunicación con el microcontrolador y a los sensores de giro de cada uno de los dedos. El esquema es el

siguiente:

Figura 23: Conexionado del MPU y de los sensores de giro

### 2.5. Dispositivo de almacenamiento:

A la hora de evaluar las alternativas en cuanto a dispositivos de almacenamiento,

surgen las alternativas de optar por un servidor web o bien por una memoria.

Por un lado, una página de internet (servidor web) permite guardar archivos o datos

a través de internet. Este servicio es administrado por un proveedor informático a través de versiones gratuitas o por una tarifa comercial. La capacidad de almacenamiento en línea dependerá de lo que el usuario requiera (en caso de ser un servicio pago), o bien si es

gratuito según lo considere el proveedor (en el caso de servidores gratuitos).

Pros de utilizar un servidor web:

- Permite compartir los archivos entre los usuarios sin tener que ocupar espacio de almacenamiento en dispositivos físicos de forma segura.

- Puede realizar copias de seguridad con la intención de preservar información importante y recuperarlos posteriormente sin complicaciones.
- No requiere montajes de ningun tipo de dispositivo extra.

Contras:

- Se necesita conocimientos profundos de HTML, CSS y de javascript para poder desarrollar la página web y poder hacer una interfaz amigable con el usuario o bien contratar un servicio para desarrollar páginas web.
- Al ser un sistema basado en la nube, es indispensable contar con acceso a internet para poder acceder a los archivos. Si el internet que se esta utilizando es lento, probablemente tenga inconvenientes a la hora de querer ver o descargar archivos almacenados. Y sencillamente, si no tienes internet, no puedes acceder de ninguna manera.
- Requiere contratar un servicio de hosting que provea el dominio de la pagina web. Además al ser un sistema que requiere bastante mantenimiento, los proveedores de este servicio pueden agregar costos según el volumen de subidas o descargas de la nube.

Por otro lado, existe la alternativa de implementar una memoria SD como dispositivo

de almacenamiento, una tarjeta SD (Secure Digital) es una tarjeta de memoria flash extraíble de dimensiones reducidas generalmente utilizadas para almacenar información

digital, como programas y archivos. Las tarjetas SD se utilizan comúnmente en teléfonos

celulares y en otros dispositivos portátiles para ampliar el almacenamiento de la memoria ROM

Pros de utilizar tarjetas de almacenamiento:

- Son pequeñas y casi no ocupan espacio.
- Formato universal compatible con todos los dispositivos.
- Intercambiables entre dispositivos.
- Alta velocidad de acceso a la información.
- Precios asequibles para capacidades intermedias.

Contras:

- Si se pierde o se daña la tarjeta se pierde la información.
- Las de mayor capacidad son excesivamente caras.
- Existen más de ocho tipos diferentes de tarjetas con usos distintos.

Los requisitos necesarios para la implementación de un servidor web en comparación con las prestaciones que ofrece hace que no tenga sentido su

implementación, razón por la cual se optó por la implementación de las memorias SD. Las opciones que se encuentran en el mercado prácticamente no varían en cuanto a las

prestaciones, por lo cual no es demasiado importante cual de los módulos adaptadores de memoria se elija, los que se implementan en esta aplicación son:

Figura 24: Modulo lector de memoria SD transmisor

Figura 25: Modulo lector de memoria SD receptor

Los módulos permitirán conectar al dispositivo de control una tarjeta de memoria SD, de forma que éste pueda almacenar grandes cantidades de datos. Esto es ideal para realizar el registro de los datos de los sensores medidos (dataloggers).

Cada módulo está diseñado para acceder a la memoria SD mediante una interfaz SPI estandar, lo cual lo hace muy versátil ya que nos permite usarlo con una amplia variedad de microcontroladores y tarjetas de desarrollo. Son compatibles con tarjetas Micro SD, tarjetas Micro SDHC (tarjeta de alta velocidad) y poseen un regulador de voltaje de 5V o 3,3V.

La memoria requiere ser formateada con formato FAT32 para funcionar con el módulo.

Tiene un total de seis pines: VCC, MOSI, MISO, SCK, CS, GND. MOSI es el pin por el que se transmiten datos hacia el otro módulo, SCK es el pin que rige la velocidad a la que se transmite cada bit, CS es el pin que señala que esta seleccionado el chip, MISO es el pin por el que se reciben los datos desde el otro módulo.

En la memoria SD por un lado se crea el archivo de texto “Lista.txt” donde se guarda la informacion que vincula las rutinas creadas con sus respectivos sensores.

El otro tipo de archivos almacenados en la memoria SD son las rutinas “Rutina_X.txt” donde se encuentran registrados los valores de los sensores del guante, muestreados a una frecuencia dada.

El orden en el que se realiza el almacenamiento es siempre el mismo: primero los acelerómetros (en el eje X, en Y y en Z), luego los giroscopios (en el eje X, en Y y en Z) y por último los valores de los sensores de los dedos del D1 al D5 (pulgar, indice, medio, anular y meñique).

Ya conociendo las caracteristicas y el funcionamiento general del módulo y el rol que cumple dentro del proyecto se procede a mostrar el esquema de conexión del mismo.

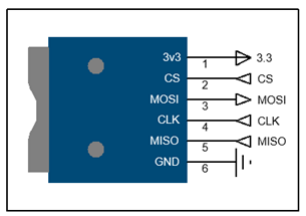
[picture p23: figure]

Figura 26: Conexionado del módulo de memoria SD

### 2.6. Transmisor/receptor

Como los dispositivos ESP32 cuentan con una antena para conexión inalámbrica, además de cumplir con el rol de circuito de control, también cuentan con los medios para

cumplir el rol de circuito transmisor y receptor. Para la comunicación entre dos dispositivos ESP32, estos modelos cuentan con un protocolo de comunicación llamado ESPNOW.

ESPNOW es un protocolo de comunicación entre varios dispositivos creados por

Espressif. Su funcionamiento requiere de emparejamiento de los dispositivos, por lo cual el “maestro” requerirá la dirección MAC del resto de dispositivos, pero una vez hecha la

conexión será automática.

ESP32 soporta las siguientes características:

- Comunicación unicast encriptada y sin encriptar.
- Se pueden mezclar clientes con encriptación y sin encriptación.
- Permite enviar hasta 250-bytes de carga útil.
- Se pueden configurar callbacks para informar a la aplicación si la transmisión fue

correcta.

- Largo alcance, pudiendo superar los 200[m] en campo abierto.

Pero también tiene sus limitaciones, las cuales son:

- El número de clientes con encriptación está limitado. Esta limitación es de 10 clientes para el modo Estación, 6 como máximo en modo punto de acceso o modo mixto.
- El número total de clientes con y sin encriptación es del 20.
- Sólo se pueden enviar 250 bytes como máximo.

Para esta aplicación solo requerimos una conexión maestro-esclavo unidireccional y

dadas las características de transmisión, este dispositivo es óptimo y logra cumplir con todas las prestaciones requeridas. Para una conexión maestro-esclavo, el dispositivo

maestro requiere la dirección MAC del ESP32 receptor para realizar el enlace de conexión.

Cada vez que se transmita un dato, parpadea alguno de los leds indicadores. Si el

dato se envía correctamente y llega al dispositivo receptor, se le envía un breve pulso al led indicador verde. En cambio, si el dato se transmite, pero no llega a destino, se le envía un pulso al led indicador rojo indicando que la comunicación está fallando.

Lo último por mencionar es que se usa un protocolo propio de comunicación y se separa la transmisión de una tarea en tres fases.

Durante la primera fase (de apertura), la estructura de datos solo contiene la información referente a la orden solicitada, esto es, el código enviado por el guante (tarea-

rutina-sensor) y además un booleano que indica que estamos en la fase 1. En esta fase, el ESP32 receptor realiza los preparativos necesarios para las demás. Esta es la única fase

requerida para las tareas 4 (cambiar sensor) y 5 (borrar rutina).

Para la segunda fase (de trabajo), se transmite la información ya sea de los sensores o de los archivos de las rutinas. Durante esta fase, el ESP32 receptor guardará los datos

en la memoria SD receptora o bien accionará los actuadores del receptor.

Por último, en la tercera fase (de cierre), el ESP32 receptor finaliza las configuraciones necesarias en los archivos y vuelve a su rutina normal.

Tras haber completado cualquiera de las órdenes de forma exitosa, los leds

indicadores van a parpadear de forma alternada indicando la finalización de la tarea

solicitada.

### 2.7. Dispositivo de control

Si bien en el mercado existen una gran variedad de microcontroladores que nos

permitan realizar las tareas de gestión y control que necesitamos para conectar todos los
bloques ya expuestos, como por ejemplo el | Raspberry pi, el | Stm32f411 o el Black Pill, | en
este proyecto se implementa como dispositivo de control (tanto en el emisor como en el

receptor) el ESP32, ya que nos brinda todas las prestaciones necesarias para cumplir con

las tareas establecidas, las siguientes son:

- Alimentación de 3.3[V] a 5[V] (los puertos de entrada soportan 3.3[V])
- Puertos de entrada analógicos suficientes para conectar los sensores de giro
- Puertos para comunicación UART (conexión con el ATMEGA328P y la pantalla TFT-LCD)
- Puertos para comunicación I2C (conexión con el sensor MPU6050)
- Puertos para comunicación SPI (conexión con el módulo lector de memoria SD)
- Comunicación inalámbrica entres dispositivos ESP32 (protocolo ESPNOW)

Se presenta a continuación el pinout del modelo del esp32 que se implementará tanto

en la placa del circuito emisor como en la placa del circuito receptor.

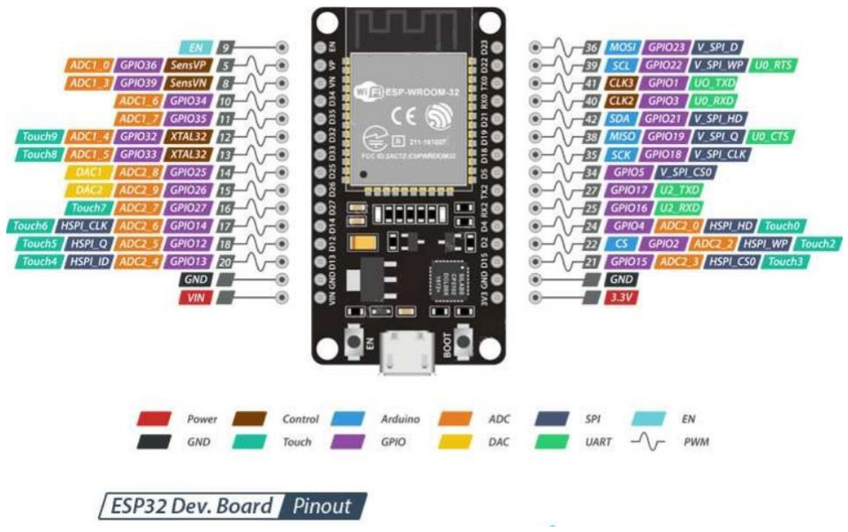
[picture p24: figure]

Figura 27: Pinout del ESP32 transmisor

A partir de este punto es necesario diferenciar entre el comportamiento del ESP32

del circuito emisor y el ESP32 del circuito receptor, ya que cada uno desempeña tareas diferentes, primero se analiza el comportamiento del ESP32 emisor y se presenta el esquemático y el diagrama de flujo del mismo para analizar su comportamiento:

Figura 28: Conexionado del ESP32 del transmisor

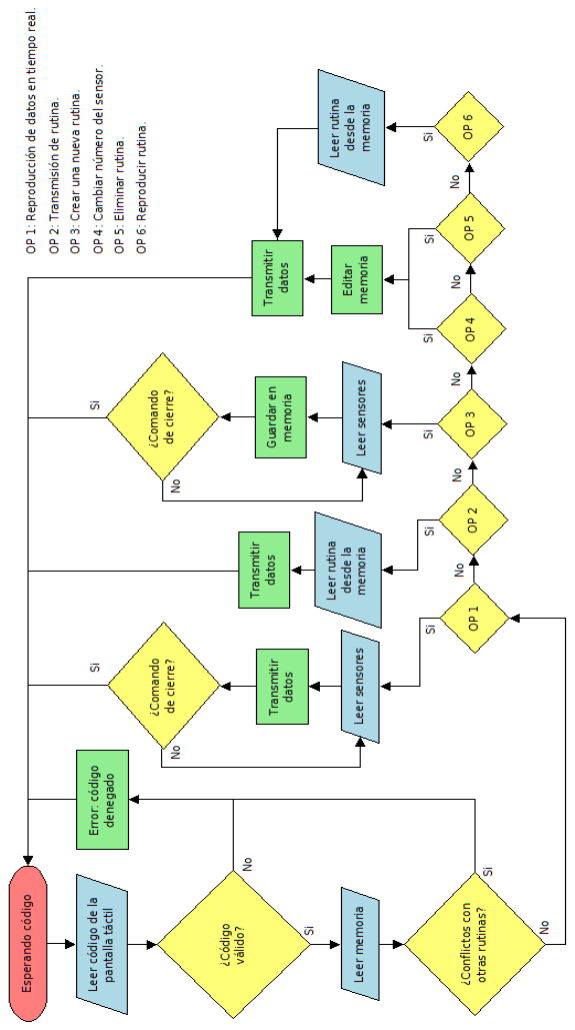
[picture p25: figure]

Figura 29: Diagrama de flujo del comportamiento del ESP32 transmisor

El ESP32 espera en todas las iteraciones a que el ATMEGA328P le envíe una orden por el puerto serial, si este no llega en una iteración del programa simplemente la finaliza. Cuando el ESP32 recibe una orden, la primera tarea a ejecutar es comprobar la sintaxis y

valores del código, a fin de descartar errores, si el código no es válido y no está dentro de lo esperado, se lo ignora y finaliza la iteración. Si en cambio el código es válido, se evalúa

entonces que la orden no entre en conflicto con los datos de la memoria, los casos que generan conflictos son:

- Intentar crear una rutina cuyo número de rutina ya fue creado previamente.
- Intentar crear una rutina con un número de sensor que ya esté en uso.
- Intentar transmitir o reproducir una rutina que no ha sido creada.
- Intentar cambiar el número del sensor a uno que ya esté en uso.
- Intentar cambiar el número del sensor de una rutina que no ha sido creada.
- Intentar borrar una rutina que no existe.

En caso de que el mensaje no sea válido o la orden entre en conflicto, los leds

indicadores parpadearán tres veces indicando la que la orden fue negada.

Si la orden se toma en cuenta, se guardan los valores del código (tarea-rutina-

sensor). Se lee el número de la tarea y según el valor del mismo, se ejecuta una rutina

acorde.

Si la tarea es 1 (transmisión de datos en tiempo real) el ESP32 lee todos los

sensores, almacena sus valores en una estructura de datos y la transmite en intervalos de 100[ms]. Esto se repite indefinidamente hasta que el usuario vuelve a tocar la pantalla táctil

y envía el código de cierre de la tarea.

Si la tarea es 2 (transmisión de rutina) el ESP32 abre desde la memoria SD el archivo

de la rutina indicada en la orden, lee su contenido tomando los valores de a once datos a la vez, los almacena en la estructura de datos y la transmite.

Si la tarea es 3 (crear rutina) lo primero que hace el ESP32 es actualizar el archivo Lista.txt, actualizando el par rutina/sensor de la nueva rutina creada, luego se crea un nuevo archivo en la memoria SD cuyo nombre será Rutina_x.txt, siendo x el número de la rutina

indicado en la orden. Para finalizar, se leen los sensores y se guardan los valores dentro del archivo creado, esto último se repite en intervalos de 100[ms] hasta que el usuario vuelve a tocar la pantalla táctil para enviar el código de cierre de la tarea.

Si la tarea es 4 (cambiar sensor) se actualiza el archivo Lista.txt con los nuevos

valores del par rutina/sensor indicado en la orden. Finalmente se cargan en la estructura de datos los valores (tarea-rutina-sensor) y se los transmite para actualizar el archivo Lista.txt

de la memoria SD del dispositivo receptor.

Si la tarea es 5 (borrar rutina) se actualiza el archivo Lista.txt cambiando el número

del sensor de la rutina indicada por un cero (esto indica que la rutina no existe) y

posteriormente borrando el archivo de rutina indicada. Finalmente, al igual que en el caso anterior, se cargan en la estructura de datos los valores (tarea-rutina-sensor) y se los transmite para actualizar el archivo Lista.txt de la memoria SD del dispositivo receptor.

Si la rutina es 6 (reproducir rutina) se lee el archivo de la rutina indicada, se cargan

los valores dentro de la estructura de datos y se la envía en intervalos de 100[ms]. Este ciclo continúa hasta que se haya leído completamente el archivo.

Por otro lado, necesitamos analizar el esquema de control del circuito receptor. Se presenta entonces el esquemático y el diagrama de flujo del mismo.

Figura 30: Conexionado del ESP32 receptor

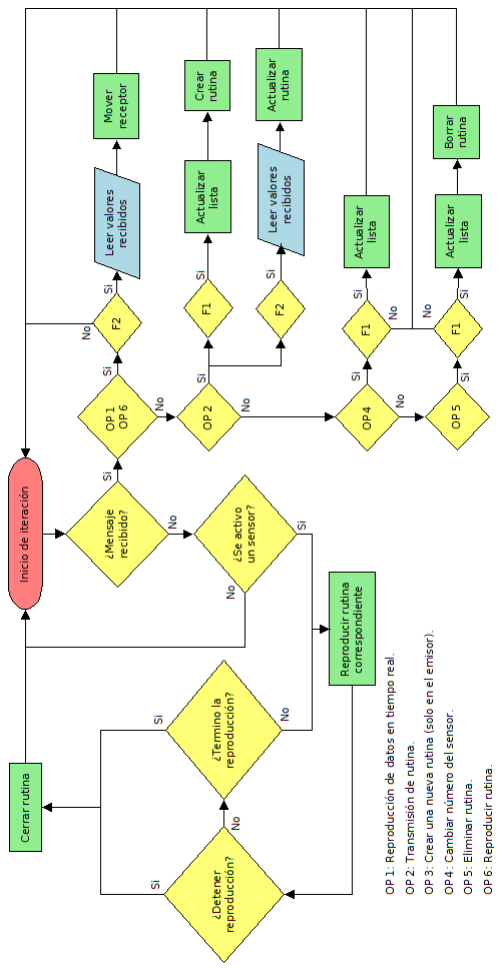
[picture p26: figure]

Figura 31: Diagrama de flujo del comportamiento del ESP32 receptor

El dispositivo de control (ESP32) del circuito receptor cumple esencialmente con las tareas de lectura de sensores y de detección de datos transmitidos.

En primer lugar y como se mencionó previamente, el ESP32 debe poder detectar los

datos que son transmitidos desde el guante e implementar una rutina en función de la orden

recibida.

Si ejecutamos la tarea 1 o 6 que son la transmisión de datos en tiempo real y la reproducción de una rutina determinada, el receptor (en ambos casos) recibe la orden y se

configura para recibir y procesar los datos adecuadamente. Posteriormente recibirá

paquetes de datos, los cuales pueden provenir de la lectura directa de los sensores del guante (tarea 1) o de los datos guardados en la memoria del guante (tarea 6). En cualquier caso, el proceso es el mismo, se leen los datos recibidos, se ajustan y filtran los valores que se salgan de los parámetros preestablecidos y se lo procesa para transformar el dato

numérico en una señal PWM capaz de controlar los motores del brazo robótico. En la fase final se indica que se ha finalizado la transmisión de datos y que el ESP32 puede volver a

su rutina normal, esperando una nueva transmisión de datos o que se active un sensor.

La tarea 2 (transmitir rutina) nos indica que el conjunto de datos leídos debe ser

guardado en memoria, por lo cual se guarda el conjunto sensor/rutina dentro del archivo Lista.txt y luego se crea un archivo donde se almacenarán los datos de la rutina que se desea crear. En la siguiente etapa los datos recibidos son guardados directamente en el archivo creado. En la fase final se cierra el archivo creado y se retorna nuevamente a la

rutina de espera.

En la tarea 4 (cambiar sensor) se edita el archivo Lista.txt, en esta instrucción se cambia el par sensor/rutina según lo que se indique en la pantalla.

La tarea 5 (eliminar rutina) edita el archivo Lista.txt eliminando el par sensor/rutina indicados. Posteriormente se elimina el archivo que contenía la rutina que se quiere borrar.

### 2.8. Procesamiento de la información (acelerómetros/giroscopios/sensores)

La información con la cual se trabaja consiste en datos obtenidos a partir de medidas realizadas con los sensores de giro y los valores de acelerómetro y giroscopio obtenidos

del MPU6050. Cada uno de ellos debe ser procesado de forma diferente al resto y se debe adaptar para que el valor obtenido pueda ser transformado en una señal de PWM capaz de

controlar correctamente los servomotores.

Antes de analizar cada caso, es importante conocer las características de la señal PWM que deseamos obtener, la misma debe tener una frecuencia de 50[Hz] (periodo de 20[ms]) y una resolución de 8 bit (varía entre 0 y 255). El duty de trabajo de la señal PWM

necesario para mover el servomotor tiene que tener un valor mínimo de 1[ms] y un valor máximo que puede variar entre 2 y 3 [ms]. Con esto en cuenta debemos procesar toda la

información de los sensores para obtener sus valores equivalentes para crear la señal

PWM, de manera similar a como se haría en un mapeo de datos.

Acelerómetros: Los acelerómetros varían (idealmente) entre un rango de -9.81 a 9.81 y representan la aceleración del dispositivo en sus respectivos ejes. En la realidad,

estos valores no son exactos y pueden presentar variaciones debido a factores físicos en la construcción del sensor por lo cual se les debe hacer pruebas para determinar su rango y posteriormente obtener los valores máximo y mínimo dentro de los cuales se desee variar

la señal PWM. Estos valores nos ayudarán a acotar el rango de valores permitidos para así descartar posibles malas lecturas y evitar un exceso de movimiento por parte de los

servomotores. Para convertir la señal otorgada por el acelerómetro en un valor aplicable en la generación de una señal PWM usamos la expresión:

a(PWM) = 13 + k

a(max) − a

a(max) − a(min)

Donde a es el valor obtenido del acelerómetro y k es una constante con la cual

podremos modificar el valor máximo que obtendremos para generar la señal PWM.

a = a(min) → a(PWM) = 13 + k

a = a(max) → a(PWM) = 13

Giroscopios: Los giroscopios miden la velocidad angular que experimenta el

MPU6050 en cada uno de sus ejes, por ejemplo, el giroscopio gx
retorna la velocidad
angular sobre el eje x (tomando el eje x como eje de giro). Este dato por si solo sirve para determinar la velocidad de movimiento del brazo, pero no para determinar su rotación total.

Para obtener la rotación realizada por el servomotor se debe integrar el dato obtenido del giroscopio. Para esto se guarda en cada iteración los valores de tiempo y velocidad

angular. Posteriormente la posición angular se mapea para transformar la rotación total leída en el valor necesario para generar la señal PWM que necesitamos para controlar el

servomotor.

θ = k(gactual − ganterior)(tactual − tanterior)

Donde k es una constante con la que configuramos la sensibilidad de respuesta del

servomotor y θ posteriormente es mapeado para que varie entre los valores precisados

para generar la señal PWM (13 a 26-39).

Sensores de giro: Los sensores de giros se comportan de manera similar a un

potenciómetro convencional. El procesamiento es similar al que se les da a los acelerómetros, primero determinamos el rango en el cual varia cada uno de ellos al mover

los dedos y con estos valores acotamos los valores válidos para evitar posibles errores de lectura (esto dependerá del diseño de los brazos usados como eje de rotación en el guante). Con todos estos datos obtenidos se aplican las mismas fórmulas usadas en el acelerómetro

reemplazando los valores de los acelerómetros por los valores de los sensores de giro.

### 2.9. Sensores del receptor

Este bloque corresponde a los sensores que serán los encargados de disparar las diferentes rutinas que se hayan guardado previamente en la memoria SD.

Antes de continuar es muy importante aclarar lo siguiente: el tipo de receptor del guante puede variar y el mismo podría ser un auto a control remoto, un dron, un periférico de videojuegos, una simulación de PC o como en nuestro caso un brazo robótico. Cada

receptor tendrá sensores y actuadores diferentes (en tipo y cantidad) los cuales brindan información y trabajan con un tipo de señal concreta, por lo que, según sea el tipo de

receptor que se desee controlar, se debe construir un circuito diferente y el código del bloque de control (ESP32) debe adaptarse para cada caso concreto.

Sin embargo, el diagrama de bloques presentado inicialmente se mantiene constante

en cada caso previsto.

El tipo de receptor implementado no tiene valor comercial, sino que fue pensado

como un modelo de demostración para exponer de la manera más sencilla posible las características buscadas en este proyecto.

Aclarado lo anterior, para el caso presentado en este proyecto no se utilizarán sensores para disparar las rutinas guardadas en la memoria SD, en cambio, se implementa

una pantalla LCD 2x16 en conjunto con dos pulsadores y un potenciómetro, los cuales le permitirán al usuario seleccionar el sensor deseado y simular su disparo.

El esquema de conexión implementado es el siguiente:


Figura 32: Conexionado de la pantalla LCD receptora

Figura 33: Conexionado de los botones de start, stop, el potenciómetro selector y el trimpot de contraste

El potenciómetro nos permite elegir el número del sensor que deseamos disparar; el

pulsador de start inicia la rutina que esté vinculada al sensor seleccionado previamente; el pulsador de stop detiene forzosamente la reproducción de una rutina y la pantalla LCD es

el medio por el cual podemos mostrarle la información necesaria al usuario.

### 2.10. Resultado final


### 2.11. Actuadores

Los actuadores utilizados en el proyecto son servomotores estándar. Éstos se

pueden controlar para girar a posiciones angulares de hasta ± 90 grados desde el reposo. La precisión angular de cada servo afecta un poco la precisión con la que se pueden mover los dedos. Cabe aclarar que en este sistema se han utilizado servomotores relativamente

económicos para mantener un bajo costo. El uso de servos de mayor calidad, por supuesto, aumentaría la fuerza y la precisión de todos los movimientos, pero costaría

significativamente más.

Los actuadores corresponden a toda la sección del circuito receptor que es

conectada a los puertos del ESP32 que entregan la señal PWM.

Lo primero que hay que conocer es el servomotor sobre el cual se desea operar. El mismo es el servomotor MG996R cuyas especificaciones de operación se detallan a

continuación:

- Corriente de operación: 500mA a 900mA (6V)
- Corriente de parada: 2.5A (6V)
- Voltaje de operación: 4.8V a 7.2V
- Frecuencia de operación de la señal PWM: 50Hz
- Amplitud de la señal PWM: 4.8V a 7.2V

Figura 34: a) Conexionado del servo b) Características de la señal PWM

Figura 35: Imagen del servomotor MG996R

Debido al gran consumo que presentan los 7 servomotores operando al mismo

tiempo, se ha optado por alimentar el circuito receptor con una fuente de tensión que sea capaz de proveer los valores especificados de tensión y corriente.

Se presenta la problemática de que la señal PWM otorgada por el ESP32 cuenta con una amplitud de 3.3V por lo cual se hace necesaria la aplicación de un conversor de nivel

que sea capaz de amplificar el voltaje al menos hasta los 4.8V. Para esto se implementó un módulo basado en el chip YF08E el cual es un conversor de tensión capaz de amplificar una señal de 3.3V hasta los 5V y cuenta con la cantidad suficiente de puertos como para

permitir trabajar con todos los servomotores.


Figura 36: Imagen del conversor de niveles lógicos

Lo último por analizar en este bloque es el brazo robótico que juega el rol de

dispositivo receptor. Como el mismo posee una complejidad considerable se lo analizará a

detalle en la siguiente sección.

### 2.12. Introducción

Se presenta un diseño imprimible en 3D para un brazo mecánico, el que será electrónicamente accionado y controlado por los datos que llegan del guante de control, ya

sea en tiempo real, o con una rutina pregrabada.

El rápido crecimiento y avance de la industria de la impresión 3D nos permite realizar

un prototipo con una calidad aceptable, para realizar los movimientos de manera bastante lineal, es decir, copiando tolerablemente los movimientos del guante.

### 2.13. Fabricación

Para crear este brazo es necesario tener un sistema mecánico bien diseñado que imite la funcionalidad del brazo humano lo mejor posible. Entre otras cosas el diseño

mecánico implica cómo se accionan las articulaciones y los tipos de fuerzas presentes en

el sistema.

Este brazo en particular usa el diseño de tendón artificial. Éstos son una forma viable

de accionar manos biónicas. Los tendones pueden soportar una alta línea de fuerza, que no se estiran cuando se tensan. Estas líneas se conectan a los dedos y son tensados por

motores en el antebrazo. Tirar de los tendones hace que los dedos se abran y cierren.

Los motores eléctricos que accionan estos tendones deben estar completamente

alojados dentro del dispositivo, para disminuir el largo innecesario de los tendones, y de esta manera minimizar la posibilidad de problemas en los movimientos.

Evaluamos con el grupo que el diseño 3d de un brazo imprimible con una impresora 3D hogareña nos iba a demandar mucho tiempo, y no hacíamos uso de los conocimientos adquiridos durante la carrera de Ingeniería Electrónica. Por esto, decidimos adquirir un

modelo que ofrece la empresa australiana Mahdi Designs, cuya licencia es educativa, y lo

adaptamos a nuestras necesidades. En este caso en particular, diseñamos solamente las dos piezas que forman el movimiento rotacional sobre el eje Z (Pieza “Engranaje Codo” y pieza “Base Codo”).

Para imprimir las piezas de este brazo se usó una impresora 3D marca Artillery, modelo SideWinder X1.

### 2.14. Dedos

Cada dedo consta de tres componentes impresos individuales unidos entre sí con pasadores de polipropileno. En un principio usamos ejes metálicos, pero evaluando el peso

del brazo terminado, decidimos cambiar el material de los mismos, para disminuir peso, y de esta manera, también disminuir el consumo de corriente necesario para mover el brazo. El tendón artificial se enrolla alrededor de la punta interior del dedo para crear un punto de

bloqueo del tendón. Este tendón pasa por canales dentro del dedo para formar un bucle cerrado. Cuando se tira del tendón, se aplican fuerzas de rotación a todas las articulaciones

y el dedo se curva hacia arriba.


Figura 37: Funcionamiento de la flexión del dedo

El punto de bloqueo del tendón es fundamental para que al tensar el tendón tire de

la punta del dedo y hace que todas las articulaciones giren. Si el tendón no se bloqueara, simplemente se deslizaría cuando tensa y el dedo no se movería. Para abrir el dedo desde una posición cerrada, se aplica tensión al otro extremo del tendón.

Se ha utilizado tanza de nylon, ya que ofrece un estiramiento mínimo cuando se tensa. Probamos también usar hilo encerado, pero notamos que, al ser más grueso, ofrecía

resistencia por rozamiento en todo su recorrido.

Los tendones de la mano humana biológica funcionan de manera similar.

Sin embargo, hay más tendones biológicos unidos a diferentes huesos, lo que

permite un control más preciso de los dedos.

### 2.15. Palma

Cada dedo se conecta a la palma mediante bujes de polipropileno. La parte inferior de la palma incorpora parte del mecanismo de rotación de la muñeca que se analiza a

continuación.

Figura 38: Imagen de la palma

### 2.16. Muñeca

El movimiento de rotación de la muñeca se logró encajando a presión la sección de

la palma directamente sobre el eje del servo en el antebrazo como se muestra a continuación.


Figura 39: Imagen del conexionado del servomotor de la muñeca con la palma

Una abertura a través del punto de pivote de esta articulación permite que los

tendones pasen desde los dedos hasta el antebrazo. Esto permite ± 90 grados de rotación sobre la muñeca.

El desafío con este diseño es proporcionar suficiente fuerza. Hubo que dejar una

gran abertura alrededor de la base del cilindro para que los tendones pasaran a medida

que la muñeca gira 180°.

Esta gran abertura concentra la tensión alrededor de la pequeña sección transversal cerca de la base de la palma.

Figura 40: Ubicación del servomotor de la muñeca dentro de la impresión 3D

Los tendones interfieren entre sí a medida que pasan a través de la pequeña abertura de la muñeca hacia los motores en el antebrazo. La rotación de la muñeca de 180° hace

que los tendones se tuerzan y se superpongan, lo que es indeseable pero no se puede evitar. Este tipo de diseño no permitiría que la muñeca rotara contínuamente, ya que

causaría que los tendones se retuerzan y se vayan enredando.


Figura 41: Detalle de los tendones en el antebrazo


Figura 42: Detalle de los tendones en la mano

### 2.17. Sistema de manejo

Los tendones se envuelven alrededor de las bobinas en el servo impresas en 3D

personalizadas creando un bucle cerrado que se muestra debajo. A medida que el servomotor gira en un sentido, tira del tendón y cierra el dedo. Para que abra el dedo, el

motor se gira en la dirección opuesta.

Figura 43: Detalle del trabajo servomotor/tendón

La imagen a continuación muestra el tendón artificial para el dedo índice. Todos los demás tendones se han omitido para mayor claridad. Los dedos pulgar, índice y medio

están conectados a servomotores. El espacio interior del brazo es limitado. El anular y el dedo meñique han sido atados al mismo servo, lo que significa que se abren y cierran en

tándem.


Figura 44: Recorrido del tendón

### 2.18. Antebrazo

Para la impresión del mismo, tuvo que dividirse en partes separadas que luego se ensamblaron con tornillos.

Figura 45: Piezas del brazo

Las dos grandes secciones del antebrazo podrían imprimirse en 3D como una sola

pieza sin afectar el montaje del dispositivo. Sin embargo, la impresora 3D no es lo suficientemente grande para imprimir un objeto de este tamaño. Las dos piezas se

imprimieron por separado y luego se aseguraron juntas con tornillos.

La sección de engranajes que se ve en la imagen de arriba es parte del mecanismo de rotación del codo. Es crucial que la calidad de este engranaje sea lo más precisa posible

en cuanto a las dimensiones. Imprimiendo el engranaje por separado, y luego pegándolo al brazo, obtenemos un engranaje impreso de mayor calidad.

### 2.19. Codo

El actuador de codo siempre debe mover el peso del antebrazo encima de cualquier carga. El par mínimo requerido para levantar el antebrazo sin carga es de aproximadamente

13,5[kg.cm]. El servo TowerPro que se utiliza proporciona 10[kg.cm] de par. Con el fin de

levantar el brazo usando un solo servo se tuvo que implementar un sistema de engranajes. Los engranajes nos permiten generar más par (fuerza de giro) a costa de perder velocidad.

El sistema de engranajes diseñado aumenta el par del servo.


Figura 46: Sistema de engranajes del codo

Para nuestro proyecto, anexamos un par de piezas necesarias para realizar el giro alrededor del eje Z, para ello se diseñaron las siguientes piezas:


Figura 47: Imagen de la pieza del “engrane codo”

Figura 48: Imagen de la pieza “base codo”


Figura 49: Ensamblaje de ambas piezas, más el engranaje y el servomotor

Dichas piezas fueron diseñadas con el software Solidworks, pudiendo lograr el

encastre perfecto con el brazo, y obteniendo una buena calidad de diseño.

Para unir ambas piezas, se usó un rodamiento marca ABR, modelo 6205. Se escogió

este modelo principalmente por el diámetro exterior (52[mm]), ya que ocupaba bien toda el área de encastre, y nos aseguramos que cumpla con la capacidad de carga estática y

dinámica (en este caso está sobredimensionado). Lo vemos en la siguiente fotografía:

Figura 50: Rodamiento ABR 6205 RS


Figura 51: Ensamble de las piezas que conforman el “hombro”

El diseño final consta de 35 componentes individuales impresos en 3D.

3 Resultados | 49

## Capítulo 3: Resultados

### 3.1. Guante de control remoto

Las prestaciones buscadas en este proyecto abarcan desde el control remoto de un dispositivo receptor en tiempo real hasta la posibilidad de crear, gestionar y reproducir un

conjunto de rutinas vinculadas a determinados sensores del dispositivo receptor.

Sin embargo, además de esto se han tenido en cuenta otros detalles como la comodidad del usuario, la reutilización del código elaborado para extrapolar el

funcionamiento a otros tipos de receptores y la sencillez del manejo del dispositivo.

En cuanto a las prestaciones técnicas del guante, el circuito es alimentado con una

fuente externa de 5[V] y 700[mA].

El comportamiento de las memorias SD en ambos circuitos es idéntico, la gestión de

los pares sensor/rutina que abarcan la creación, cambio de par y eliminación de rutinas, se maneja mediante el archivo “Lista.txt” y los datos de cada rutina concreta son almacenados

en un archivo exclusivo para la misma.

La transmisión de la información es llevada a cabo mediante el protocolo ESP-NOW propia de los dispositivos ESP32. Además, se le incorpora al guante un par de leds

indicadores que nos brindan información sobre el estado de la transmisión de datos, sobre

posibles errores en los módulos del guante y sobre los permisos necesarios para ejecutar

determinadas acciones. Los patrones programados en los leds son los siguientes:

- Falla en la lectura de la memoria SD: Parpadeo del led rojo de 1[Hz] de frecuencia con duty del 10%.
- Falla en la lectura del MPU6050: Parpadeo del led rojo de 1[Hz] de frecuencia con duty del 90%.
- Transmisión exitosa: Por cada paquete de datos enviado, parpadea el led verde.
- Transmisión fallida: Por cada paquete de datos enviado, parpadea el led rojo.
- Operación inválida: Ambos ledes parpadean tres veces.
- Operación finalizada: Ambos ledes parpadean alternadamente durante 2 segundos

Por otro lado, la pantalla táctil funciona de manera fluida y suave. Además, la interface presentada en la pantalla se ha simplificado al máximo, permitiendo de este modo

al usuario un control práctico e intuitivo del guante.

3 Resultados | 50

La estructura impresa en 3D para conectar los sensores de giro con los dedos se diseñó y desarrolló de manera tal de que el usuario no las sienta en lo más mínimo mientras opera con el guante.

Finalmente, el código desarrollado fue pensado para su reutilización con otros dispositivos receptores y se prestó énfasis en omitir por completo el delay en las funciones

clave de lectura y operación de datos del programa, logrando en su proceso un funcionamiento fluido, robusto y veloz.

El resultado final, según lo planteado en un inicio, es un guante capaz de leer la flexión de todos los dedos, su posición y movimientos relativos en el espacio. El mismo

opera en tiempo real o gestiona las rutinas de la memoria SD según lo designe el usuario en las tareas disponibles en la interface de la pantalla táctil. El guante es cómodo, permite una buena movilidad y puede funcionar con uno o varios dispositivos en simultáneo, el único

cambio que se debe realizar es sobre la codificación del mismo ya que se debe especificar el código MAC del ESP32 que jugara el rol de receptor en el otro circuito.

### 3.2. Modulo receptor

En cuanto al receptor, que incluye solo el circuito de control, se alimenta con una fuente de PC con 5[V] capaz de suministrar un gran amperaje debido al alto consumo de

los servomotores.

El dispositivo receptor desarrollado fue modificado especialmente para propósitos de

exposición, por lo cual en lugar de usar sensores o pulsadores para ejecutar las rutinas guardadas en la memoria SD, se emplea un menú con una pantalla LCD de 2x16

comandada con el controlador HD44780, un potenciómetro que permite simular el número del sensor que se desea activar y un par de pulsadores los cuales pueden iniciar la rutina vinculada al sensor seleccionado y detener forzosamente dicha rutina.

### 3.3. Brazo robótico

El brazo robótico presentado, fue impreso en una impresora 3D hogareña. Se

asemeja a un brazo humano, en los movimientos de los dedos, la muñeca y el codo. La articulación que correspondería al hombro, es un movimiento rotatorio limitado a un solo

eje. El movimiento de las articulaciones está efectuado por servomotores, que enrollan los tendones correspondientes a cada articulación. El control de estos motores está

3 Resultados | 51

comandado por el módulo receptor antes descripto. La alimentación de estos servomotores se efectuó con una fuente de 5[VCC].

### 3.4. Notas especiales

El dispositivo receptor desarrollado fue modificado especialmente para propósitos de exposición y su único valor real, (al menos en cuanto a ejecución de rutinas) es meramente

didáctico. Esto puede no suponer ningún problema si lo que se busca es exclusivamente el control remoto del dispositivo receptor, sin embargo, si se desea trabajar con las modalidades que emplean las memorias SD, es necesario que el receptor cuente con algún sensor o pulsador que sea capaz de ejecutar el evento para la reproducción de las rutinas

almacenadas en ellas.

5 Discusión y Conclusión | 52

## Capítulo 4: Análisis de Costos

### 4.1. Análisis de costos

En esta sección se analizan los costos de producción de las distintas partes que componen el guante y el brazo robótico. Los costos dados en todas las tablas están estimados en dólares.

Las piezas del brazo robot fueron hechas en su totalidad con PLA+ de la marca Grilon, se estima aproximadamente un consumo de 1281 gramos de filamento y tardo uno

total de 159 horas con 22 minutos

Tabla 1: Tiempos y costo de la impresión del brazo

Pieza | Gramos | Tiempo (hs) | Tiempo (min) | Cantidad | min totales
01_biceps | 170 | 19 | 16 | 1 | 1156
02_Upper bicep cap | 94 | 10 | 13 | 1 | 613
03_Locking Pins | 4 | | 36 | 2 | 72
04_Pin Lock | 1 | | 12 | 2 | 24
05_Small Gear | 10 | 1 | 29 | 2 | 178
06_Index finger | 19 | 3 | 3 | 1 | 183
07_Middle finger | 18 | 3 | 13 | 1 | 193
08_Pinky finger | 10 | 1 | 50 | 1 | 110
09_Ring finger | 18 | 3 | 10 | 1 | 190
10_Thumb finger | 27 | 3 | 54 | 1 | 234
11_Mid Forearm Large | 127 | 13 | 49 | 1 | 829
12_Mid Forearm Small | 39 | 4 | 54 | 1 | 294
13_Upper Forearm Small | 18 | 2 | 9 | 1 | 129
14_wrist clearance A y B | 2 | | 12 | 1 | 12
15_Wrist Forearm Section A | 19 | 2 | 11 | 1 | 131
16_Wrist Forearm Section B | 9 | 1 | 16 | 1 | 76
17_Palm_Optimised Connector | 68 | 9 | 42 | 1 | 582
18_Palm Finger Cutouts Back | 29 | 2 | 55 | 1 | 175
19_Forearm Gear Split | 29 | 3 | 10 | 1 | 190
20_Upper Forearm Large | 187 | 20 | 33 | 1 | 1233
21_Upper Forearm Small | 18 | 2 | 8 | 1 | 128
base codo | 181 | 21 | 52 | 1 | 1312
engranaje codo | 180 | 22 | 30 | 1 | 1350
22_Horn | 4 | | 42 | 4 | 168
| 1281 | 144 | 659 | 30 | 9562

Teniendo en cuenta el costo estimado de trabajo de un ingeniero Junior ($289819 o

U$D956,5), obtenemos un valor de servicio de unos USD 5,98 la hora. A continuación, se

5 Discusión y Conclusión | 53

muestran las tablas del costo de los materiales y la fabricación de cada una de las unidades

que componen el producto, incluyendo en las mismas, el valor del servicio prestado:

Tabla 2: Costos de fabricación del guante

Materiales | Costo x Unidad | Cantidad | Total
Guante | 4,57 | 1 | 4,57
Sensor de giro | 6,85 | 5 | 34,24
ESP32 | 12,41 | 1 | 12,41
Atmega328P | 17,71 | 1 | 17,71
MPU6050 | 5 | 1 | 5
Pantalla TFT | 7,96 | 1 | 7,96
PLA | 10,19 | 0,07 kg | 0,71
Lector de memoria SD | 2,23 | 1 | 2,23
Memoria SD 2GB | 2,36 | 1 | 2,36
Horas de impresión | 0,01 | 3 | 0,04
| | Total | 87,33

Tabla 3: Costos de fabricación del brazo robot

Material | Costo X Unidad | Modelo | Cantidad | Total
Servomotores | 2,95 | m90s | 5 | 14,73
Servomotores | 5,48 | 996r | 1 | 5,48
PLA+ | 20,91 | | 1,281 Kg | 26,79
Horas de impresión | 0,02 | | 158,366 | 2,37
| | | Total | 51,60

5 Discusión y Conclusión | 54

Tabla 4: Costos de fabricación del circuito receptor

Material | Costo X Unidad | Cantidad | Total
Placa | 1,59 | 1 | 1,59
ESP32 | 12,41 | 1 | 12,41
Jumpers hembra | 1,27 | 1 | 1,27
Jumpers macho | 1,27 | 1 | 1,27
Potenciómetro | 0,96 | 1 | 0,96
Botones | 0,14 | 2 | 0,29
Trimpot | 0,40 | 1 | 0,40
Display LCD | 15,47 | 1 | 15,47
Nivelador lógico | 1,59 | 1 | 1,59
Lector de memoria SD | 2,23 | 1 | 2,23
Memoria SD 2GB | 2,36 | 1 | 2,36
| | Total | 39,84

Al costo obtenido de las tablas anteriores que representan el coste de producción por unidad, se les debe incorporar el costo agregado de las horas invertidas en el diseño y desarrollo del guante.

El costo de producción de una unidad es de U$D178,77 considerando solo la materia

prima, a esto se le agrega un costo de producción de 4 horas de trabajo por cada uno de nosotros, resultando en un costo agregado de U$D70,12 para un total de U$D248,89.

Al precio del producto le agregamos el costo del tiempo que invertimos en la

investigación, diseño y desarrollo que es aproximadamente de dos meses de trabajo con jornada completa para tres ingenieros junior, agregando un costo de inversión de U$D5806,45.

El costo agregado será amortizado en la venta de las primeras 1000 unidades, aumentando el costo por unidad en U$D5,6 y dando un total de U$D254,5.

5 Discusión y Conclusión | 55

### 4.2. Plan de Venta:

4.2.1. Público objetivo.

Es una herramienta de automatización orientada al área industrial, sin embargo, este

prototipo permite darle una gran flexibilidad y con ello la capacidad de poder ampliar su público objetivo y su área de aplicación hacia las áreas del entretenimiento y la educación.

4.2.2. Objetivos y plan de acción.

Ya que este es un nuevo producto en el mercado no posee fuerza de venta, entonces

el primer objetivo planteado es el de dar a conocer el producto para obtener nuevos clientes. Para darnos a conocer y conseguir nuevos clientes es mediante el uso de redes sociales con las cuales es posible armar un perfil de nuestra empresa donde podemos colocar la

descripción del producto, ingresar nuestro sitio web, ingresar nuestro número de contacto, administrar las interacciones con los clientes, publicar sobre novedades de nuestra

empresa, impulsar tus publicaciones y hacer anuncios. Todos los anuncios que se van a mostrar van a tener la dirección de nuestra tienda propia la cual también va a ser un punto

de venta donde vamos a atender a los clientes y donde posteriormente vamos a sacar prototipos pequeños para probar incursionar en el área del entretenimiento. El objetivo es

que nuestro producto llegue a los dueños de empresas que requieran controlar procesos de automatización mediante la implementación de robots o brazos robóticos. Otro tipo de

cliente pueden ser los centros educativos con orientación técnica, en las cuales el producto

pueda a estimular el interés de los alumnos por la programación y la electrónica al poder ver físicamente una aplicación del mismo.

Otro objetivo es el de recuperar el costo de las inversiones realizadas en la etapa de

diseño. La medida tomada es el de amortizar el costo de inversión y agregarlo al costo de

venta de las primeras 1000 unidades.

Posteriormente, debemos mejorar los procesos de diseño y construcción del guante, de manera tal que nos permita reducir los costos de inversión por unidad y de esta forma

abaratar costos y ser más competitivos en el mercado.

Lo último por el momento es desarrollar nuevos prototipos que permitan que el

producto pueda aplicarse en otros mercados, ya que tiene muchísimo potencial y presenta muchas prestaciones.

5 Discusión y Conclusión | 56
Capítulo 5: Discusión y Conclusión.
5.1. Resultados obtenidos.

Las prestaciones generales obtenidas principalmente en el guante logran cumplir satisfactoriamente con los requisitos que se le han impuesto desde un inicio. Cumple con los protocolos mínimos de seguridad y el diseño final resulta cómodo y práctico a

comparación de las versiones anteriores desarrolladas.

La codificación, junto a los módulos utilizados, brindan las bases fundamentales para

el funcionamiento íntegro del dispositivo. Aun así, no se descartan posibles mejoras en cuando a la selección de los módulos, siempre buscando minimizar el consumo, reducir el

tamaño o simplificar el funcionamiento general del guante.

En cuanto al dispositivo receptor que se conecta al brazo robótico, como se mencionó antes, cuenta con los medios necesarios para brindarle al usuario un control total en cuanto al disparo y ejecución de las rutinas almacenadas, no obstante, se vuelve a recalcar, es impráctico para todo propósito excepto como dispositivo de demostración y pruebas, que es lo desarrollado en este proyecto.

5.2. Objetivos propuestos vs objetivos hallados.

En un principio el propósito del proyecto consistía en la elaboración de un sistema

de guardado y reproducción de datos que pueda ser aplicado en medios industriales de producción. Los resultados obtenidos a lo largo de su elaboración nos hacen pensar que

mediante unos pequeños ajustes, este dispositivo es capaz de cumplir con las tareas para el cual fue diseñado en un principio, sin embargo, la misma naturaleza del proyecto demostró tener el potencial de ser usado en otros ámbitos para los que no fue pensado en

un inicio y esto mismo le brinda el potencial de escalarlo y mediante pequeños ajustes incursionar en otras áreas que puedan ser explotadas mediante el uso de un periférico de

estas características, principalmente en las áreas de educación y entretenimiento ya que puede ser conectado de manera muy sencilla a una gran variedad de dispositivos

receptores.
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

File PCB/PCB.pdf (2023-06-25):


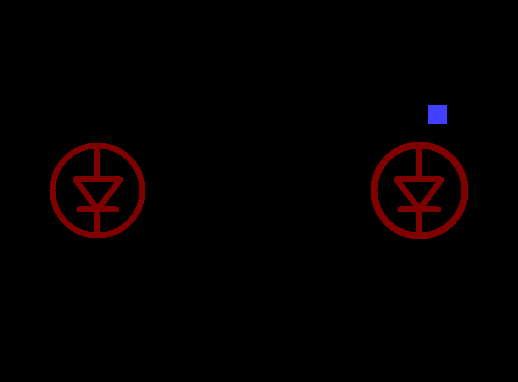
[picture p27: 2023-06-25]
Informes/gif/transmision exitosa.gif

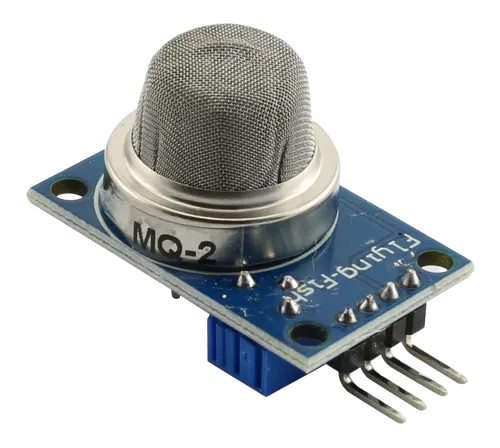
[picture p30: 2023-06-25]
sensores/sensor_de_humo-removebg-preview.png

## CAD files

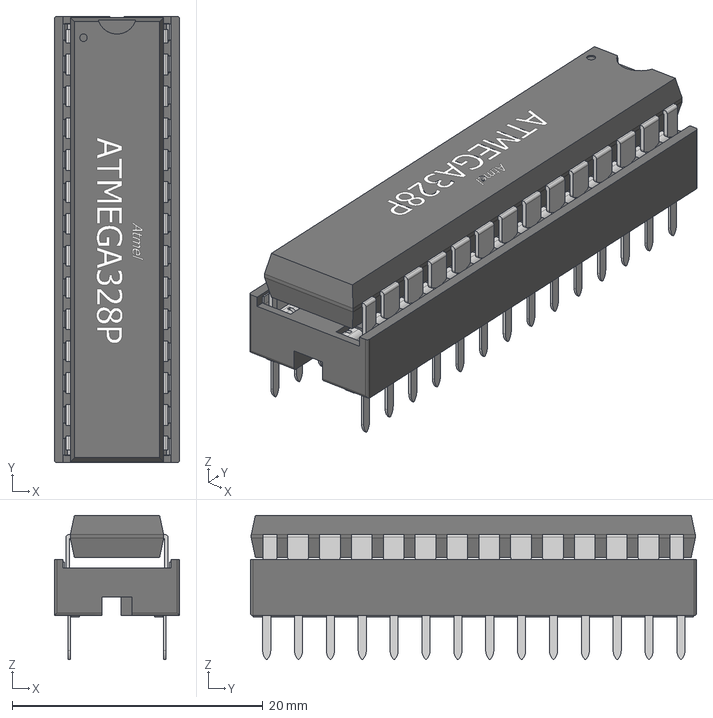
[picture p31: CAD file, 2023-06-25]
PCB/Modelos 3D/Atmega328P/ATMEGA328p_Socket.stp
10.0 x 35.5 x 11.5 mm

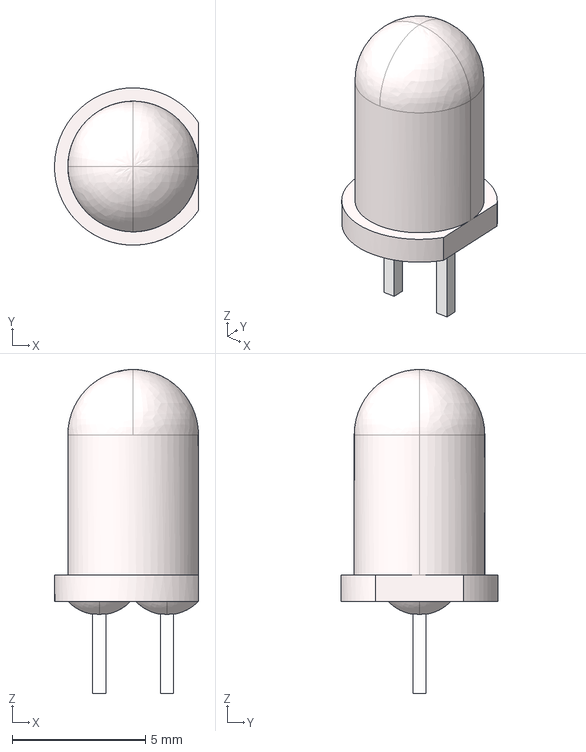
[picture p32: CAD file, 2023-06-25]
PCB/Modelos 3D/Leds/LED 5mm white TH.stp
5.40 x 5.90 x 12.1 mm

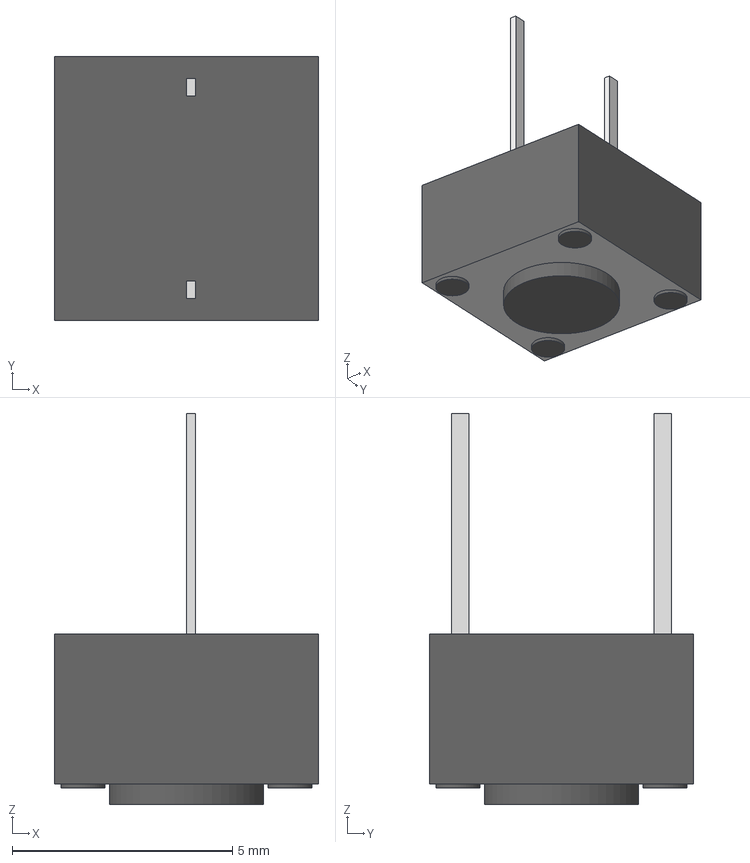
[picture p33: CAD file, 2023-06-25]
PCB/Modelos 3D/PushButton/PushButton2.step
6.00 x 6.00 x 8.87 mm
Cilindro004
Cilindro003
Cilindro002
Cilindro001
Pin2
Pin
Cilindro
Cuerpo

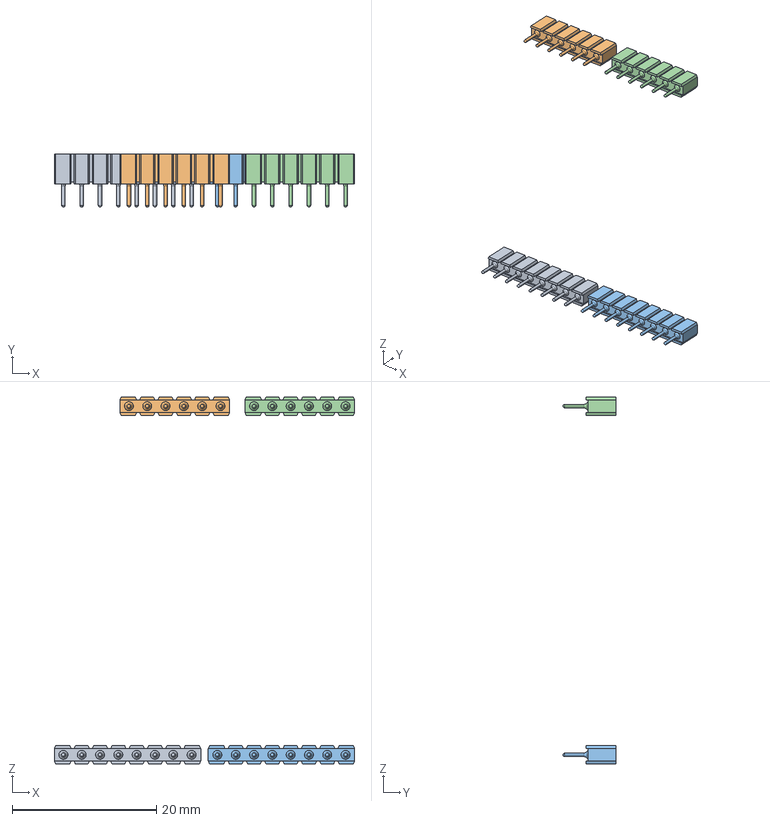
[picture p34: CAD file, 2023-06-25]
PCB/Modelos 3D/Socalo pantalla TFT/Socalo pantalla TFT.FCStd
41.7 x 7.37 x 50.9 mm
Socalo 8-1
Socalo 6-1
Socalo 8-2
Socalo 6-2

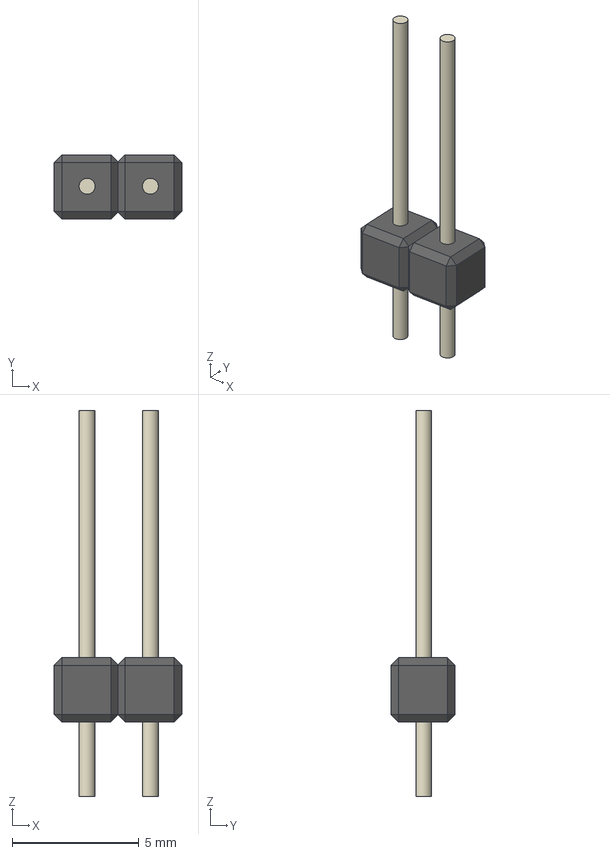
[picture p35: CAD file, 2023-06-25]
PCB/Modelos 3D/Socalos para pines/Socalo.step
5.04 x 2.54 x 15.2 mm
Cilindro002
Cilindro001

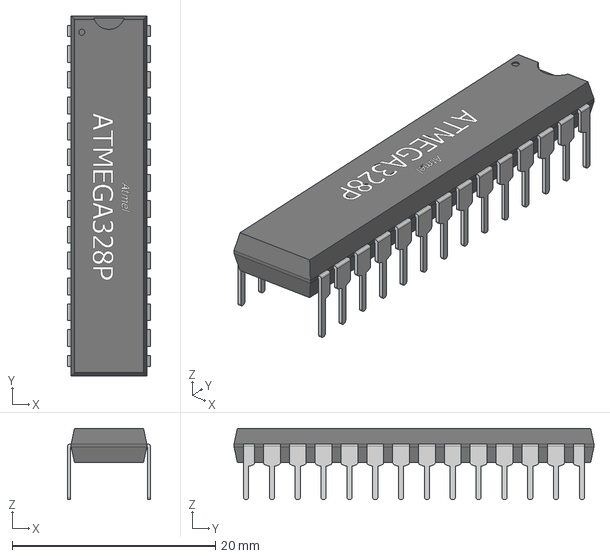
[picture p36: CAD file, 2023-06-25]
PCB/Modelos 3D/Atmega328P/ATMEGA328p.stp
8.13 x 35.4 x 6.99 mm

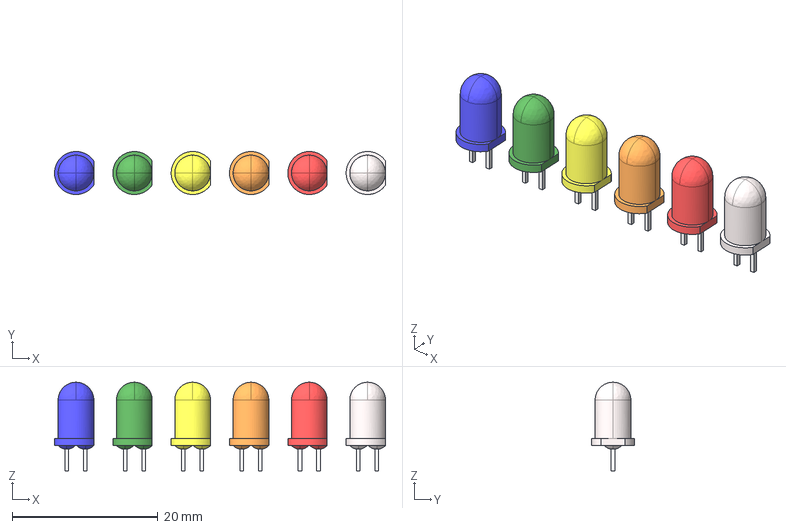
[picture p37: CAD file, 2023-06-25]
PCB/Modelos 3D/Leds/LED's 5mm TH.stp
45.4 x 5.90 x 12.1 mm

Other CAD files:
PCB/Modelos 3D/Leds/LED 5mm blue TH.stp
PCB/Modelos 3D/Leds/LED 5mm purple TH.stp
PCB/Modelos 3D/Leds/LED 5mm light blue TH.stp
PCB/Modelos 3D/Leds/LED 5mm red TH.stp
PCB/Modelos 3D/Leds/LED 5mm yellow TH.stp
PCB/Modelos 3D/Leds/LED 5mm light green TH.stp
PCB/Modelos 3D/Leds/LED 5mm green TH.stp
PCB/Modelos 3D/Leds/LED 5mm pink TH.stp
PCB/Modelos 3D/Leds/LED 5mm orange TH.stp
PCB/Modelos 3D/PushButton/PushButton2.FCStd
PCB/Modelos 3D/PushButton/PushButton2.blend
PCB/Modelos 3D/PushButton/PushButton2.obj
PCB/Modelos 3D/PushButton/PushButton2.stl
PCB/Modelos 3D/PushButton2.blend
PCB/Modelos 3D/Socalo pantalla TFT/Socalo pantalla TFT.obj
PCB/Modelos 3D/Socalo pantalla TFT/Socalo pantalla TFT.stl
PCB/Modelos 3D/Socalo pantalla TFT/Socalo pantalla.blend
PCB/Modelos 3D/Socalos para pines/Socalo.FCStd

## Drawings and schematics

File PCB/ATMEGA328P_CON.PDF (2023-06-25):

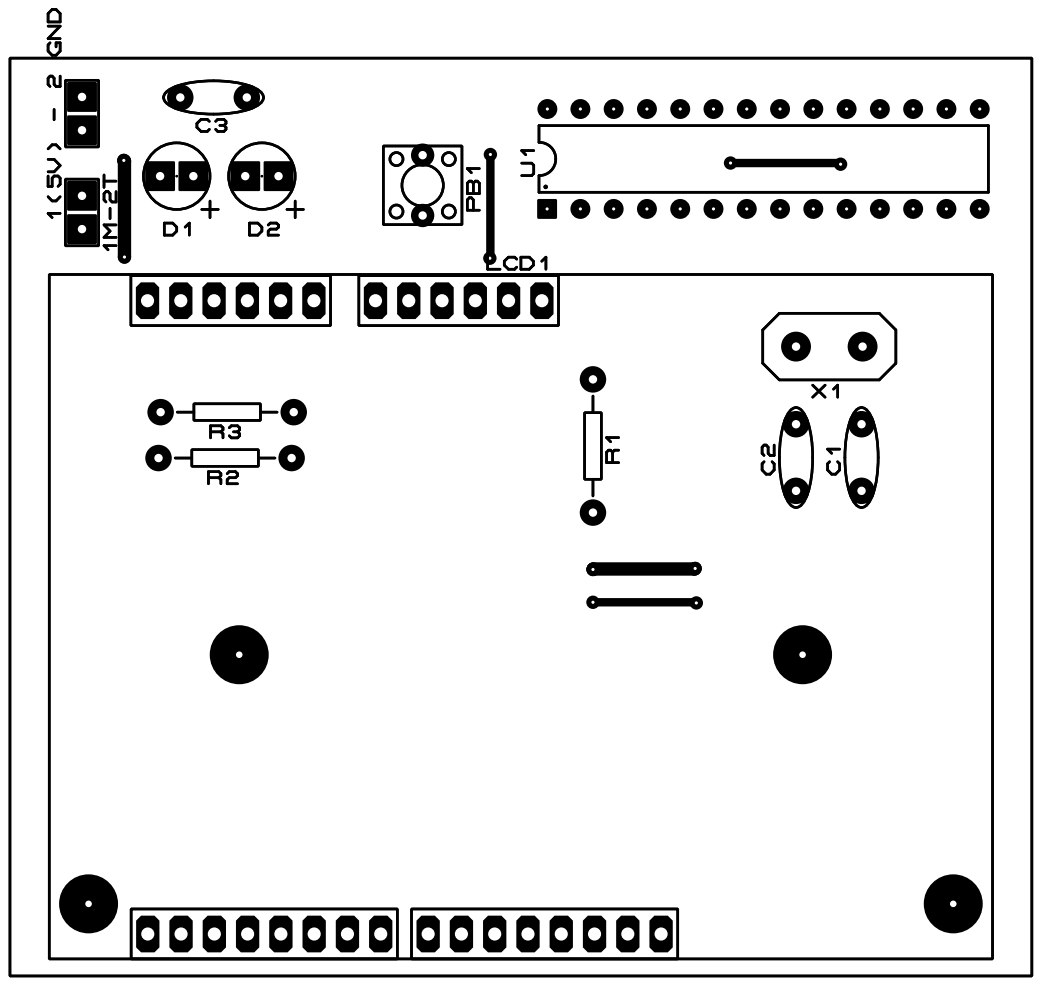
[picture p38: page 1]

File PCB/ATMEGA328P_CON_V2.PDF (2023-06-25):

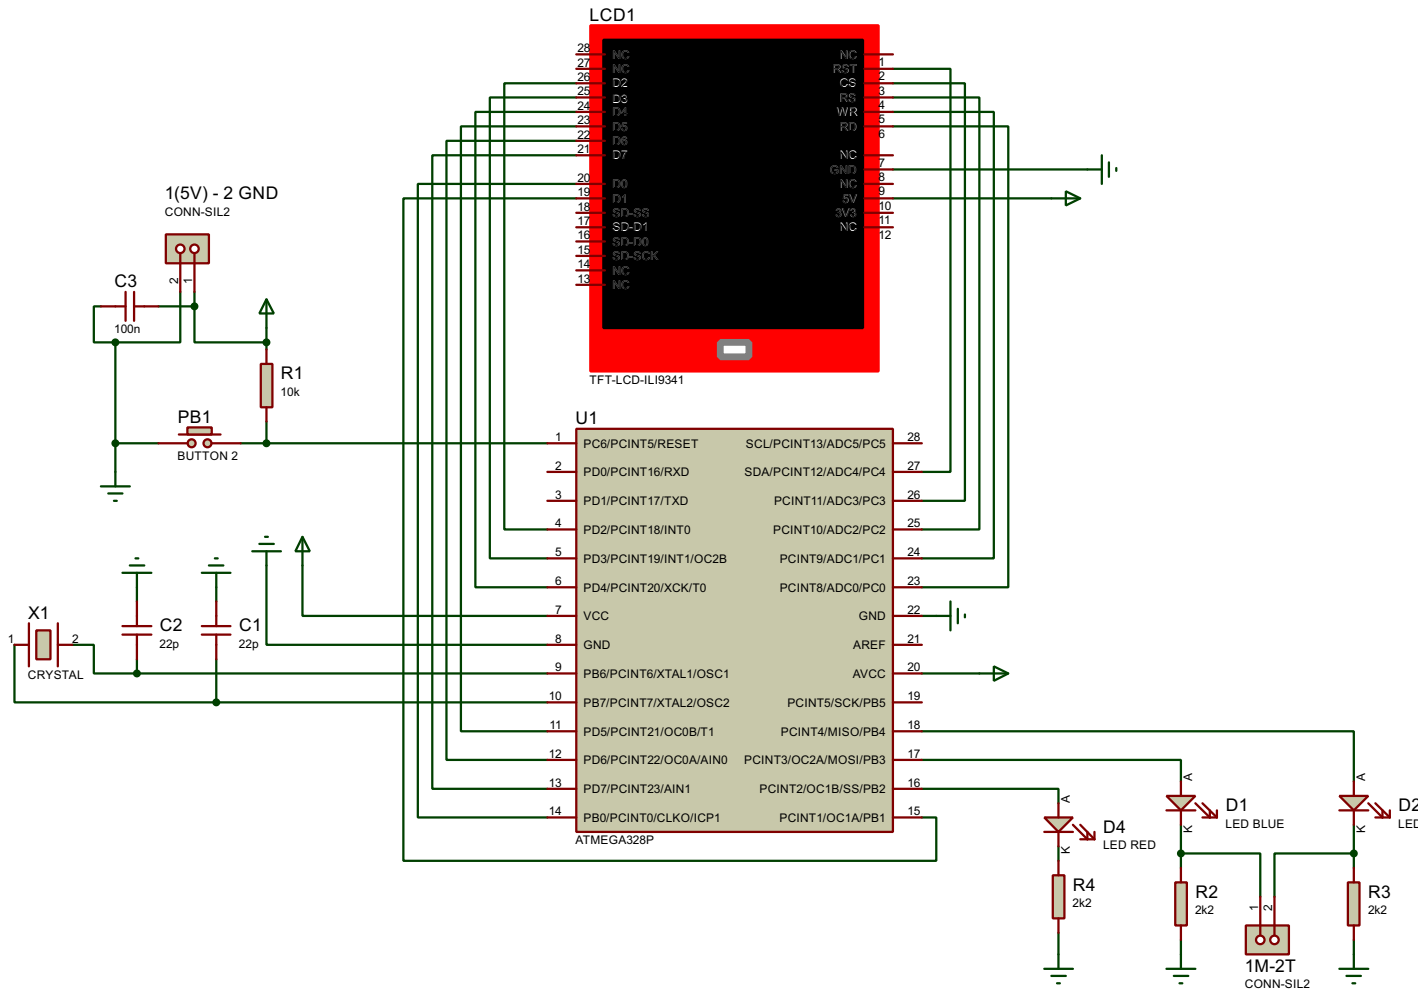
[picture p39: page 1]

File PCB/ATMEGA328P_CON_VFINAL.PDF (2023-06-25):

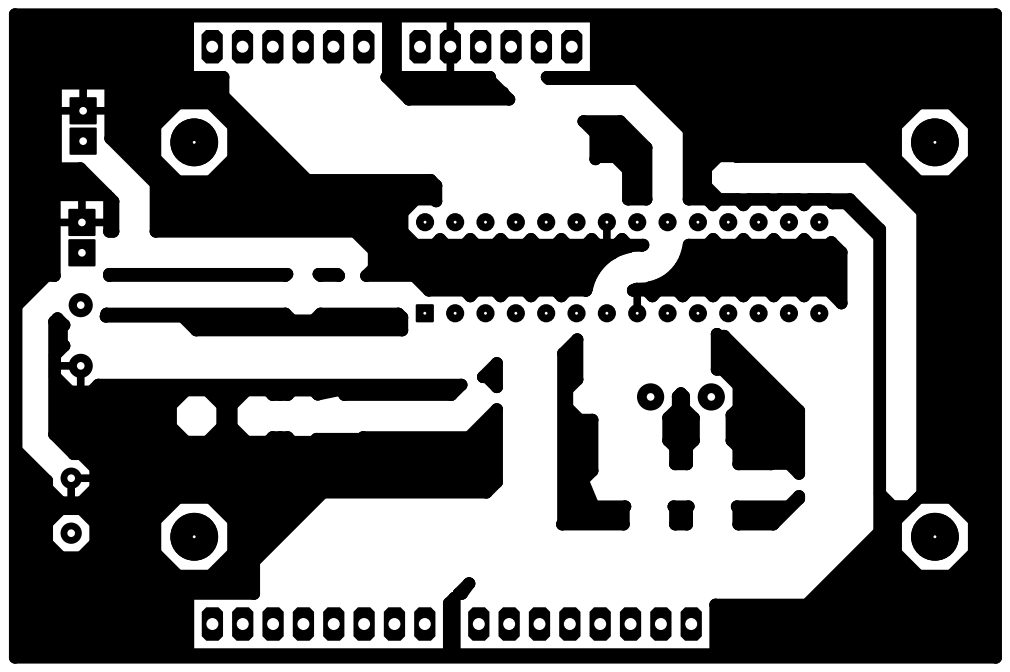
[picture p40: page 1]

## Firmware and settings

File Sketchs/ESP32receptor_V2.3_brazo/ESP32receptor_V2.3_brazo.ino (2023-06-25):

// DECLARACION DE LIBRERIAS ****************************************************************************************
#include "FS.h"
#include "SD.h"
#include "SPI.h"
#include <esp_now.h>
#include <WiFi.h>
#include <LiquidCrystal.h>

// PUERTOS DE LA PANTALLA LCD **************************************************************************************
#define RS_4     22 
#define E_6      23 
#define D4_11    5 
#define D5_12    18 
#define D6_13    19 
#define D7_14    21

// PUERTOS DE LA MEMORIA SD ****************************************************************************************
#define SD_SCK   14
#define SD_MISO  27
#define SD_MOSI  13
#define SD_CS    15
SPIClass spiSD(HSPI); // Especificamos que vamos a usar el puerto HSPI para la memoria SD

// PUERTOS DEL POTENCIOMETRO SELECTOR DE RUTINA Y PULSADORES DE INICIO Y PARADA DE REPRODUCCION ********************
#define POTE_SELECT_RUTINA 36
#define BTN_INICIAR_RUTINA 39
#define BTN_DETENER_RUTINA 34

// PUERTOS DE LOS SERVOMOTORES *************************************************************************************
#define PIN_SERVO_1 17 //SERVO1 = hombro
#define PIN_SERVO_2 16 //SERVO2 = elevacion
#define PIN_SERVO_3 4  //SERVO3 = muñeca 
#define PIN_SERVO_4 32 //SERVO4 = pulgar
#define PIN_SERVO_5 33 //SERVO5 = indice
#define PIN_SERVO_6 25 //SERVO6 = mayor
#define PIN_SERVO_7 26 //SERVO7 = meñique

// CONFIGURACION DE LAS PROPIEDADES DE LA SEÑAL PWM ****************************************************************
#define CANAL_1  1 //PWM - hombro
#define CANAL_2  2 //PWM - elevacion
#define CANAL_3  3 //PWM - muñeca
#define CANAL_4  4 //PWM - meñique/anular
#define CANAL_5  5 //PWM - mayor
#define CANAL_6  6 //PWM - indice
#define CANAL_7  7 //PWM - pulgar              D26
#define RESOLUCION_PWM  8  // La señal tendra una resolucion de 8 bits, 256 valores posibles
#define FRECUENCIA_PWM  50 // Los servos trabajan en periodos de 20ms con duty entre 1ms y 2ms

// ESTRUCTURAS *****************************************************************************************************
struct s_receiveData
{ // Estructura implementada para la transmision de datos
  short sensor, rutina, estado; // estado >> (1) tiempo real  ; (2) transmitir rutina ; (3) crear rutina ; (4) cambiar sensor ; (5) borrar rutina 
  float ax,ay,az,gx,gy,gz;
  float d1,d2,d3,d4,d5;
  bool b_esDato; // Booleano que indica si la estructura enviada son datos de lista o no
};
typedef struct s_receiveData s_ReceiveData; 

s_ReceiveData myReceiveData; // Instanciamos las estructuras para almacenar los datos de la lista para la memoria, 

// CONSTANTES ******************************************************************************************************
#define DELAY_RECCONFIG 2000 // Duracion de la recepcion de la estructura myreceiveData

// VALORES LIMITE DE LOS DISTINTOS SENSORES ************************************************************************
#define VAL_PULGAR_RELAX 3000
#define VAL_PULGAR_FLEX 2200
#define VAL_INDICE_RELAX 2700
#define VAL_INDICE_FLEX 1800
#define VAL_MEDIO_RELAX 2700
#define VAL_MEDIO_FLEX 1650
#define VAL_MENIQUE_RELAX 2850
#define VAL_MENIQUE_FLEX 1850
#define VAL_AY_MIN -10
#define VAL_AY_MAX 0


// DECLARACION DE VARIABLES ****************************************************************************************
File archivo; // Referencia a los archivos creados dentro de la memoria
LiquidCrystal lcd( RS_4 , E_6 , D4_11 , D5_12 , D6_13 , D7_14 ); 
short lista[18];            // Contenido actualizado del archivo Lista.txt con valores en ASCII >> r1s1r2s2r3s3...r8s8r9s9 (0-48 ; 9-57)
short sensorSeleccionado=0; // Indica el sensor seleccionado que el usuario desea activar
short faseActual = 0;       // fase de recepcion de datos (1)-configuracion ; (2)-datos ; (3)-configuracion
short faseAnterior = 0;     // valor de la fase del loop anterior
short modoDeReproduccion=0; // Indica si se esta reproduciendo alguna rutina en el brazo segun los siguientes valores
/* 0 - No se esta reproduciendo nada  ;  1 - Reproduciendo en tiempo real  ;  2 - Reproduciendo una rutina desde la memoria SD*/
bool b_recibiendo;          // indica si en este loop se esta recibiendo informacion mediante el protocolo ESPNOW
bool b_cambioDeFase;        // indica si en este loop se cambio de fase
long ultimoDatoRecibido;    // indica el momento en el cual se ha recibido el ultimo dato desde el transmisor

float ajusteFlexion = 9;     // flexion >> ajusta la sensibilidad
float ajusteRotacion = 9;    // muñeca >> ajusta la sensibilidad
float ajusteIndice = 13;          // indice >> ajusta el rango de movimiento  
float ajusteMenique = 13;         // menique >> ajusta el rango de movimiento  
float ajusteMedio = 30;           // Medio >> ajusta el rango de movimiento  
float ajustePulgar = 13;          // Pulgar >> ajusta el rango de movimiento  
float ajusteElevacion = 13;       // elevacion >> ajusta el rango de movimiento  


// CABECERAS DE FUNCIONES ******************************************************************************************
// Actualiza la variable modoDeReproduccion
void actualizarModoDeReproduccion();
// Configura los puertos de entrada y salida del ESP32
void configurarPuertos();
// Configura los puertos y canales PWM con las propiedades necesarias para funcionar con los motores del brazo 
void configurarPWM();
// Crea una nueva rutina dentro de la memoria SD
void crearNuevaRutina();
// Edita el contenido del archivo lista.txt segun lo almacenado en la estructura myReceiveData
void editarArchivoLista();
// Escribe en una nueva linea el String "contenido" al final del archivo "nombre" 
void escribirAlFinal(String nombre, String contenido);
// Carga los datos de la estructura dentro del archivo de la rutina correspondiente
void escribirArchivo();
// Escribe en la pantalla LCD los String Col1 y Col2 en las columnas 1 y 2 respectivamente
void escribirEnPantallaLCD(String col1, String col2);
// Actualiza el valor de los booleanos acorde a la estapa actual de cada orden
void gestorDeBooleanos();
// Actualiza el valor de la fase de recepcion de datos actual 0-nada ; 1-config ; 2-dato ; 3-config
void gestorDeFase(); 
// Busca y retorna el numero de la rutina vinculado el numero del sensor s
short getRoutine(short s);
// Lee el potenciometro selector de sensores y retorna el sensor seleccionado segun sea el valor del potenciometro
short getSensor();
// Configura el Esp32 del receptor para que pueda recibir datos normalmente
void iniciarESPNOW();
// Inicializacion de la memoria SD
void iniciarMemoriaSD();
// Inicializacion de la pantalla LCD
void iniciarPantallaLCD();
// Lee el valor del potenciometro, lo procesa y actualiza el valor de la rutina en la pantalla LCD acorde al valor indicado
void LCD_actualizarPantalla();
// Lee el archivo Lista.txt y actualiza su contenido dentro del vector global >> lista[18]
void leerLista();
// Puesta a cero del brazo
void puestaCero();
// Genera una señal PWM y mueve el motor anexado al d1 
void PWMd1(float valorSensor);
// Genera una señal PWM y mueve el motor anexado al d2 
void PWMd2(float valorSensor);
// Genera una señal PWM y mueve el motor anexado al d3 
void PWMd3(float valorSensor);
// Genera una señal PWM y mueve el motor anexado al d5 
void PWMd5(float valorSensor);
// Genera una señal PWM y mueve el motor anexado al movimiento de elevacion del brazo 
void PWMelevacion(float ay);
// Genera una señal PWM y mueve el motor anexado al movimiento de rotacion del brazo
void PWMrotacion(float gy); 
// Genera una señal PWM y mueve el motor anexado al movimiento de flexion del brazo
void PWMflexion(float gx); 
// Reproduce (si existe) la rutina numero "num" de la memoria SD 
void reproducirRutina(short num);
// Indica si se ha pulsado el boton BTN_DETENER_RUTINA
bool routineStopped();
// Indica si se ha pulsado el boton BTN_INICIAR_RUTINA
bool routineStarted();
// Modifica el archivo Rutina.txt eliminando el sensor de la rutina almacenada en myReceiveData
void rutinaBorrarRutina();
// Rutina que modifica el archivo Lista.txt y cambia el valor del sensor de la rutina indicada en myReceiveData
void rutinaCambiarSensor();
// Gestiona las tareas correspondientes acorde a la creacion de una nueva rutina
void rutinaCrearRutina();
// Ejecuta las sub-rutinas acorde a la configuracion recibida desde el emisor 
void rutinaDeEstados(); 
// // Gestiona la rutina acorde a la reproduccion de datos en tiempo real
void rutinaTiempoReal();

// Carga la estructura con los datos recibidos mediante el protocolo ESPNOW
// ----------------------------------------------------------------------------------------------------------------
void OnDataRecv(const uint8_t * mac_addr, const uint8_t *incomingData, int len) 
{
  memcpy(&myReceiveData, incomingData, sizeof(myReceiveData));
  b_recibiendo = true; // indica si se esta recibiendo informacion mediante el protocolo ESPNOW
  ultimoDatoRecibido = millis();
}

// ----------------------------------------------------------------------------------------------------------------
void pruebaDeRangoPWM(short minimo, short maximo){
  bool desdeBase = true , desdeTecho = false;
  float valor = minimo; 
  while(true){
    if(desdeBase){
      while(valor<=maximo){
        valor ++;
        ledcWrite(CANAL_7, valor);
        delay(100);
      }
      desdeTecho = true;
      desdeBase = false;
    } else if(desdeTecho){
        while(valor>=minimo){
        valor --;
        ledcWrite(CANAL_7, valor);
        delay(100);
      }
      desdeTecho = false;
      desdeBase = true;
    }
  }
}

// ----------------------------------------------------------------------------------------------------------------
void pruebaDeRotacion(){

  float gx = myReceiveData.gx; // flexion -3 , extension +3
  float gy = myReceiveData.gy; // palma arriba -7 , palma abajo +7
  float ax = myReceiveData.ax; // palma abajo -9.8 , palma arriba +9.8 
  float ay = myReceiveData.ay; // mano vertical -9.8 , mano horizontal 0 

  float ax_min = -9.8;
  float ax_max = 9.8;
  float ay_min = -9.8;
  float ay_max = 0;
  
  short gx_min = -3; 
  short gx_max = 3; 
  short gy_min = -7; 
  short gy_max = 7; 
  
  // MOVIMIENTO ELEVANDO EL BRAZO
  if(ay < ay_min) ay = ay_min; 
  else if(ay > ay_max) ay = ay_max; 

  //float pwm = ((float)((ay_max - ay)/(ay_max - ay_min))+1)*13; // debe variar entre 13 y 26
  float pwm = ((float)((ay_max - ay)/(ay_max - ay_min))+1)*17;
  ledcWrite(CANAL_7, pwm);
  
  delay(20);
  
}


void setup()
{
  Serial.begin(115200);
  iniciarESPNOW();
  iniciarPantallaLCD();
  iniciarMemoriaSD();
  configurarPuertos();
  configurarPWM();

  // pruebaDeRangoPWM(13,40);
  // pruebaDeRotacion();
  // pruebaDeFlexion();
}

void loop()
{
  gestorDeFase(); // Modifica la fase de recepcion de datos actual 0-nada ; 1-config ; 2-dato ; 3-config
  gestorDeBooleanos(); // Actualiza el valor de los booleanos acorde a la estapa actual de cada orden

  if(b_recibiendo)
  { // Codigo a ejecutar cuando estamos recibiendo datos desde el ESP32 emisor
    b_recibiendo = false; // Con esto me aseguro que entre solo en los loops donde se reciben datos
    rutinaDeEstados(); // Ejecuta las sub-rutinas acorde a la configuracion recibida desde el emisor 
  } 
  
  else
  { // Codigo a ejecutar por defecto - Lee los sensores conectados al receptor
    /*actualizarModoDeReproduccion();*/ 
    //0 - No reproduciendo nada  ;  1 - Reproduciendo en tiempo real  ;  2 - Reproduciendo rutina desde memoria SD

    LCD_actualizarPantalla(); // Actualiza el mensaje de la pantalla LCD 
    
    if(modoDeReproduccion == 2)
    { // Ejecutamos cuando se ha pulsado el boton de reproduccion de rutinas BTN_INICIAR_RUTINA    
      reproducirRutina(getRoutine(getSensor())); // Reproducimos la rutina vinculada al sensor marcado en la pantalla LCD
      // reproducirRutina(short num);  Reproduce (si existe) la rutina numero "num" de la memoria SD 
      // getRoutine(short s); Retorna el numero de la rutina vinculada al sensor s, segun el archivo Lista.txt
      // getSensor(); retorna el numero del sensor marcado en la pantalla LCD      
    }
  }
}
// ----------------------------------------------------------------------------------------------------------------
void actualizarModoDeReproduccion()
{ // Actualiza la variable modoDeReproduccion
  modoDeReproduccion = 0;
  if(routineStarted()) modoDeReproduccion = 2;
}
// ----------------------------------------------------------------------------------------------------------------
void configurarPuertos()
{ // Configura los puertos de entrada y salida del ESP32
  pinMode(POTE_SELECT_RUTINA,INPUT);
  pinMode(BTN_INICIAR_RUTINA,INPUT);
  pinMode(BTN_DETENER_RUTINA,INPUT);
  pinMode(PIN_SERVO_1, OUTPUT);
  pinMode(PIN_SERVO_2, OUTPUT);
  pinMode(PIN_SERVO_3, OUTPUT);
  pinMode(PIN_SERVO_4, OUTPUT);
  pinMode(PIN_SERVO_5, OUTPUT);
  pinMode(PIN_SERVO_6, OUTPUT);
  pinMode(PIN_SERVO_7, OUTPUT);
}
// ----------------------------------------------------------------------------------------------------------------
void configurarPWM()
{ // Configura los puertos y canales PWM con las propiedades necesarias para funcionar con los motores del brazo 
// Configuracion de las funcionalidades de la señal PWM
  ledcSetup(CANAL_1, FRECUENCIA_PWM, RESOLUCION_PWM);
  ledcSetup(CANAL_2, FRECUENCIA_PWM, RESOLUCION_PWM);
  ledcSetup(CANAL_3, FRECUENCIA_PWM, RESOLUCION_PWM);
  ledcSetup(CANAL_4, FRECUENCIA_PWM, RESOLUCION_PWM);
  ledcSetup(CANAL_5, FRECUENCIA_PWM, RESOLUCION_PWM);
  ledcSetup(CANAL_6, FRECUENCIA_PWM, RESOLUCION_PWM);
  ledcSetup(CANAL_7, FRECUENCIA_PWM, RESOLUCION_PWM);
  // attach the channel to the GPIO to be controlled
  ledcAttachPin(PIN_SERVO_1, CANAL_1);
  ledcAttachPin(PIN_SERVO_2, CANAL_2);
  ledcAttachPin(PIN_SERVO_3, CANAL_3);
  ledcAttachPin(PIN_SERVO_4, CANAL_4);
  ledcAttachPin(PIN_SERVO_5, CANAL_5);
  ledcAttachPin(PIN_SERVO_6, CANAL_6);
  ledcAttachPin(PIN_SERVO_7, CANAL_7);  
}
// ----------------------------------------------------------------------------------------------------------------
void crearNuevaRutina()
{ // Crea una nueva rutina dentro de la memoria SD
  short rutina = myReceiveData.rutina; // Numero de la rutina que deseamos crear
  String nombreArchivo = "/Rutina_" + (String)rutina + ".txt"; // Nombre del archivo que quremos crear
  archivo = SD.open(nombreArchivo, FILE_WRITE);
  archivo.close(); 
}
// ----------------------------------------------------------------------------------------------------------------
void editarArchivoLista()
{ // Edita el contenido del archivo lista.txt segun lo almacenado en la estructura myReceiveData

  Serial.println("editarArchivoLista()  >>  Iniciando la funcion");  //!!!!!!!!!!!!!!!!!!!!!!!!!!!!!!!!!!!!!!!!!!!!!!!!!!! ACTIVAR PARA PRUEBAS                                                  //!!!!!!!!!!!!!!!!!!!!!!!!!!!!!!!!!!!!!!!!!!!!!!!!!!! ACTIVAR PARA PRUEBAS
  
  short sensor = myReceiveData.sensor + 48; // Valor leido del sensor (en ascii)
  short rutina = myReceiveData.rutina; // Valor leido de la rutina

  Serial.println("editarArchivoLista()  >>  ""rutina:"+(String)rutina+" , sensor:"+(String)(sensor-48));  //!!!!!!!!!!!! ACTIVAR PARA PRUEBAS                                                     

  archivo = SD.open("/Lista.txt",FILE_WRITE);
  lista[2*rutina-1] = sensor;
  for(int i=0;i<9;i++)
  { // Escribe los datos del string dentro del archivo lista.txt
    archivo.print((char)lista[2*i]); 
    archivo.print('-');  
    archivo.println((char)lista[2*i+1]);
  } // fin >> for(i=0;i<9;i++)
  archivo.close(); 

  Serial.println("editarArchivoLista()  >>  lista.txt actualizado");  //!!!!!!!!!!!!!!!!!!!!!!!!!!!!!!!!!!!!!!!!!!!!!!!!!!! ACTIVAR PARA PRUEBAS                                                     
}
// ----------------------------------------------------------------------------------------------------------------
void escribirAlFinal(String nombre, String contenido)
{ // Escribe en una nueva linea el String "contenido" al final del archivo "nombre" 
  archivo = SD.open(nombre, FILE_APPEND); // Abrimos el archivo en modo reescritura
  if(archivo) archivo.println(contenido); // Si se abrio correctamente, agregamos contenido al final del mismo
  archivo.close();
}
// ----------------------------------------------------------------------------------------------------------------
void escribirArchivo()
{ // Carga los datos de la estructura myReceiveData dentro del archivo de la rutina correspondiente
  short rutina = myReceiveData.rutina; // Numero de la rutina que deseamos crear
  String nombreArchivo = "/Rutina_" + (String)rutina + ".txt"; // Nombre del archivo que quremos crear

  archivo = SD.open(nombreArchivo, FILE_APPEND); // Agregamos un dato al final
  archivo.println((float)myReceiveData.ax);
  archivo.println((float)myReceiveData.ay);
  archivo.println((float)myReceiveData.az);
  archivo.println((float)myReceiveData.gx);
  archivo.println((float)myReceiveData.gy);
  archivo.println((float)myReceiveData.gz);
  archivo.println((float)myReceiveData.d1);
  archivo.println((float)myReceiveData.d2);
  archivo.println((float)myReceiveData.d3);
  archivo.println((float)myReceiveData.d4);
  archivo.println((float)myReceiveData.d5);

  archivo.close(); 
}
// ----------------------------------------------------------------------------------------------------------------
void escribirEnPantallaLCD(String col1, String col2)
{ // Escribe en la pantalla LCD los String Col1 y Col2 en las columnas 1 y 2 respectivamente
  lcd.clear();
  lcd.setCursor(0,0);
  lcd.print(col1);
  lcd.setCursor(0,1);
  lcd.print(col2);
}
// ----------------------------------------------------------------------------------------------------------------
short getRoutine(short s)
{ // Busca y retorna el numero de la rutina vinculado el numero del sensor s, segun el archivo Lista.txt
  leerLista(); // Lee el archivo Lista.txt y actualiza su contenido dentro del vector global >> lista[18]
  /*
  Serial.print("Lista actual: ");
  Serial.print(lista[0]-48); Serial.print("-");
  Serial.print(lista[1]-48); Serial.print(" ; ");
  Serial.print(lista[2]-48); Serial.print("-");
  Serial.print(lista[3]-48); Serial.print(" ; ");
  Serial.print(lista[4]-48); Serial.print("-");
  Serial.print(lista[5]-48); Serial.print(" ; "); 
  Serial.print(lista[6]-48); Serial.print("-");
  Serial.print(lista[7]-48); Serial.print(" ; ");
  Serial.print(lista[8]-48); Serial.print("-");
  Serial.print(lista[9]-48); Serial.print(" ; ");   
  Serial.print(lista[10]-48); Serial.print("-");
  Serial.print(lista[11]-48); Serial.print(" ; ");
  Serial.print(lista[12]-48); Serial.print("-");
  Serial.print(lista[13]-48); Serial.print(" ; ");  
  Serial.print(lista[14]-48); Serial.print("-");
  Serial.print(lista[15]-48); Serial.print(" ; ");  
  Serial.print(lista[16]-48); Serial.print("-");
  Serial.println(lista[17]-48);
  */
  short ret; // valor de retorno
  int i = 0;
  for(i==0; i<9; i++)
  {
    if(lista[2*i+1]-48 == s) 
    {
      ret = lista[2*i]-48;
      /*
      Serial.print("Rutina "); Serial.println(lista[2*i]-48);
      Serial.print("Sensor "); Serial.println(lista[2*i+1]-48);
      */
    }
  }
  return ret;
}
// ----------------------------------------------------------------------------------------------------------------
short getSensor()
{  // Lee el potenciometro selector de sensores y retorna el sensor seleccionado segun sea el valor del potenciometro
  short val = analogRead(POTE_SELECT_RUTINA);
  if(val < 455) return 1;
  else if(val < 910) return 2;
  else if(val < 1365) return 3;
  else if(val < 1820) return 4;
  else if(val < 2275) return 5;
  else if(val < 2730) return 6;
  else if(val < 3185) return 7;
  else if(val < 3640) return 8;
  else return 9;
}
// ----------------------------------------------------------------------------------------------------------------
void gestorDeBooleanos()
{ // Actualiza el valor de los booleanos acorde a la estapa actual de cada orden

  //************ Cambios de fase dentro del modo 2 ***************
  // Primer loop del modo 2 - fase 1
  if(faseActual != faseAnterior && faseActual == 1 && myReceiveData.estado == 2) b_cambioDeFase = true;
  // Primer loop del modo 2 - fase 2
  else if(faseActual != faseAnterior && faseActual == 2 && myReceiveData.estado == 2) b_cambioDeFase = true;
  // Primer loop del modo 2 - fase 3
  else if(faseActual != faseAnterior && faseActual == 3 && myReceiveData.estado == 2) b_cambioDeFase = true;

  //*************** En caso de que no haya cambios de fase de ningun tipo *********************
  else {b_cambioDeFase=false;}

  // Actualizamos el valor de la faseActual anterior y terminamos el loop
  faseAnterior=faseActual; 
}
// ----------------------------------------------------------------------------------------------------------------
void gestorDeFase()
{ // Modifica la faseActual de recepcion de datos actual 0-nada ; 1-config ; 2-dato ; 3-config
  if(faseActual!=0 && millis()-ultimoDatoRecibido > DELAY_RECCONFIG)
  { // Se ejecuta si ha pasado un tiempo DELAY_RECCONFIG desde que se recibio el ultimo dato
    faseActual = 0;
  } else if(faseActual==0 && !myReceiveData.b_esDato && b_recibiendo)
  { // Se ejecuta cuando pasamos de la faseActual 0 a la faseActual 1 en un loop en el cual recibimos datos
    faseActual = 1;
  } else if(faseActual == 1 && myReceiveData.b_esDato && b_recibiendo)
  { // Se ejecuta cuando pasamos de la faseActual 1 a la faseActual 2 en un loop en el cual recibimos datos
   faseActual = 2;
  } else if(faseActual == 2 && !myReceiveData.b_esDato && b_recibiendo)
  { // Se ejecuta cuando pasamos de la faseActual 2 a la faseActual 3 en un loop en el cual recibimos datos
   faseActual = 3;
  }
}
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

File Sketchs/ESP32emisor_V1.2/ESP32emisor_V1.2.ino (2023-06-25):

/* 
 *
 ******************************************************************************************************************
 * PROTOCOLO DE MENSAJES POR EL PUERTO SERIAL
 *    SINTAXIS >> A-R-S
 *    A >> ACCION ESTABLECIDA (1 = transmitir en tiempo real) 
 *                            (2 = transmitir una rutina de la memoria (crear rutina en el receptor))  
 *                            (3 = crear una nueva rutina (solo en la memoria del transmisor))
 *                            (4 = cambiar el numero del sensor de alguna de las rutinas )
 *                            (5 = borrar rutina) (de la memoria del guante y del brazo)
 *                            (6 = reproducir rutina) (reproduce la rutina seleccionada en el brazo)
 * 
 *    R >> Numero de la rutina seleccionada para los estados (2, 4, 5), en caso de ser innecesaria vale cero
 * 
 *    S >> Numero del sensor seleecionado para los estados (3, 4, 6), en caso de ser innecesaria vale cero
 ****************************************************************************************************************** 
 *
 * SECUENCIA DE GUARDADO DE DATOS
 * ax - ay - az - gx - gy - gz - d1 - d2 - d3 - d4 - d5 
 *
 */
// estado >> (0) tiempo real  ; (1) transmitir rutina ; (2) crear rutina ; (3) cambiar sensor ; (4) borrar rutina 

// LIBRERIAS ------------------------------------------------------------------------------------------------------
#include <esp_now.h>          // Libreria de comandos de transmision para el protocolo ESPNOW
#include <WiFi.h>             // Libreria de comandos para configurar el ESP32
#include <Adafruit_MPU6050.h> // Libreria de instrucciones para el control del MPU6050
#include <Adafruit_Sensor.h>  
#include "FS.h"
#include "SPI.h"
#include "SD.h"

// DEFINICIONES DE PUERTOS ----------------------------------------------------------------------------------------
// Pines
#define Rx 16          // Puerto de transmision para la comunicacion UART con el Atmega328P
#define Tx 17          // Puerto de recepcion para la comunicacion UART con el Atmega328P
#define D1 36          // Puerto conectado al sensor del dedo meñique
#define D2 39          // Puerto conectado al sensor del dedo anular
#define D3 34          // Puerto conectado al sensor del dedo medio
#define D4 35          // Puerto conectado al sensor del dedo indice
#define D5 32          // Puerto conectado al sensor del dedo pulgar
#define LED_OK 12      // Puerto conectado a un led indicador
#define LED_ERROR 13   // Puerto conectado a un led indicador
#define CS 5
#define MOSI 23
#define CLK 18
#define MISO 19

// CONSTANTES -----------------------------------------------------------------------------------------------------
#define DELAY_TRANSCONFIG 200 // Cada cuanto tiempo se transmite la estructuras mySendConfig
#define DELAY_TRANSDATA 100 // Cada cuanto tiempo se transmite la estructura mySendData
#define DELAY_SENDCONFIG 2000 // Duracion de la transmision de la estructura mySendconfig
#define DELAY_TRANS_MODO_6 3 // Delay entre los sucesivos envios del modo 6 (reproducir rutina) editar y ajustar este valor
// Teclas para la visualizacion de datos de la estructura >> metodo showData()
char tecla;
bool ac_X = false, ac_Y = false, ac_Z = false, gy_X = false, gy_Y = false, gy_Z = false;
bool ti_X = false, ti_Y = false, ti_Z = false;
bool D_1 = false, D_2 = false, D_3 = false, D_4 = false, D_5 = false; 
bool Mode = false;

// Direccion MAC del ESP32 receptor del mensaje
uint8_t RxMACaddress[] = {0x78 , 0x21 , 0x84 , 0x91 , 0x2D , 0xD0}; 

// ESTRUCTURAS ----------------------------------------------------------------------------------------------------
struct s_sendData
{ // Estructura implementada para la transmision de datos
  short sensor, rutina, estado;
  float ax,ay,az,gx,gy,gz;
  float d1,d2,d3,d4,d5;
  bool b_esDato; // Booleano que indica si la estructura enviada son datos de sensores o no
};

typedef struct s_sendData s_SendData; 

// VARIABLES ------------------------------------------------------------------------------------------------------
Adafruit_MPU6050 mpu;     // Referencia a las madidas realizadas por el modulo MPU6050
File archivo;             // Referencia a los elementos dentro de la memoria
String str_nombreArchivo; // Nombre del archivo con el cual se desea trabajar (usar solo en las rutinas)
String str_puertoSerial;  // Almacena la cadena enviada desde el Atmega328P 

short estadoAnterior;     // Almacena el valor de la variable estado del loop anterior
short lista[18];          // Contenido actualizado del archivo Lista.txt con valores en ASCII >> r1s1r2s2r3s3...r8s8r9s9 (0-48 ; 9-57)

s_SendData mySendData;     // Instanciamos las estructuras para almacenar los datos de la lista para la memoria, 

bool finEstado = false; // Indica el final del estado a mediante la secuencia_A()
bool B_E1_P1 = false; // Booleano auxiliar que indica que debemos enviar la primera parte del codigo mySendConfig (2s)
bool B_E1_P2 = false; // Booleano auxiliar que indica que debemos enviar la segunda parte del codigo mySendData
bool B_E1_P3 = false; // Booleano auxiliar que indica que debemos enviar la tercera y ultima parte del codigo mySendConfig (2s)
bool B_E1_P4 = false; // Booleano auxiliar que indica que debemos enviar la secuencia que indica el final de la rutina
bool B_E2_P1 = false; // Booleano auxiliar que indica que debemos transmitir mySendConfig antes de enviar la rutina
bool B_E2_P2 = false; // Booleano auxiliar que indica que debemos transmitir la rutina solicitada
bool B_E2_P3 = false; // Booleano auxiliar que indica que debemos transmitir mySendConfig despues de enviar la rutina
bool B_E3_P1 = false; // Booleano auxiliar que indica que debemos actualizar el archivo lista
bool B_E3_P2 = false; // Booleano auxiliar que indica que debemos crear y llenar con datos el nuevo archivo de la rutina
bool B_E4_P1 = false; // Booleano auxiliar que indica que debemos cambiar el numero del sensor de la rutina seleccionada
bool B_E4_P2 = false; // Booleano auxiliar que indica que debemos transmitir la informacion sobre los cambios recientes
bool B_E5_P1 = false; // Booleano auxiliar que indica que debemos borrar una rutina y actualizar el archivo Lista.txt
bool B_E5_P2 = false; // Booleano auxiliar que indica que debemos transmitir la informacion sobre los cambios recientes
bool B_E6_P1 = false; // Booleano auxiliar que indica que debemos transmitir la configuracion de la rutina 6
bool B_E6_P2 = false; // Booleano auxiliar que indica que debemos transmitir el contenido de la rutina seleccionada
bool B_E6_P3 = false; // Booleano auxiliar que indica la finalizacion del estado 6

// CABECERAS DE FUNCIONES -----------------------------------------------------------------------------------------

// Actualiza el archivo lista.txt con el cambio y eliminar el archivo de la rutina seleccionado
void borrarRutina();

// Configura los puertos de entrada y salida del ESP32 
void configurarPuertos();
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
